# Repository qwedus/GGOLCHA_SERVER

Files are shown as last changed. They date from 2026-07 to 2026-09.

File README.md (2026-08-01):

# GGOOLCHA Telemetry System

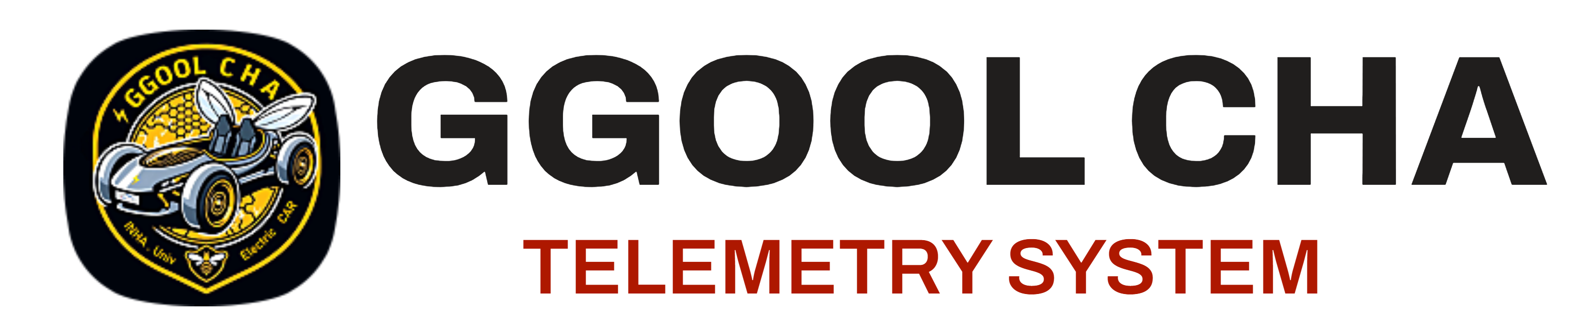
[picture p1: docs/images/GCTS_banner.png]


DIY wireless data logging platform for Team GGOOLCHA

## Features

* 📡 Full wireless support
   * Real-time telemetry
   * Download recorded data 
   * Transmit User Events
   * Transmit CAN messages
   * Configure device (e.g. CAN bit rate)

* 📀 Up to 100 Hz data rate with various signals
   * 1x CAN 2.0(A/B)
   * 1x External GPS
   * 1x Internal 6-axis Accelerometer & Gyroscope
   * 4x Digital input channels
   * 6x Analog input channels
   * 1x Power supply voltage sensor
   * 1x Chip temperature sensor

* 💡 Customizable web-based data analysis tool
* 🍺 Fully Open-source & Open-hardware under the Beerware license

## Preview

[Web Control Hub](https://v2.monolith.luftaquila.io) for live telemetry, data viewer and device/ui configurations.

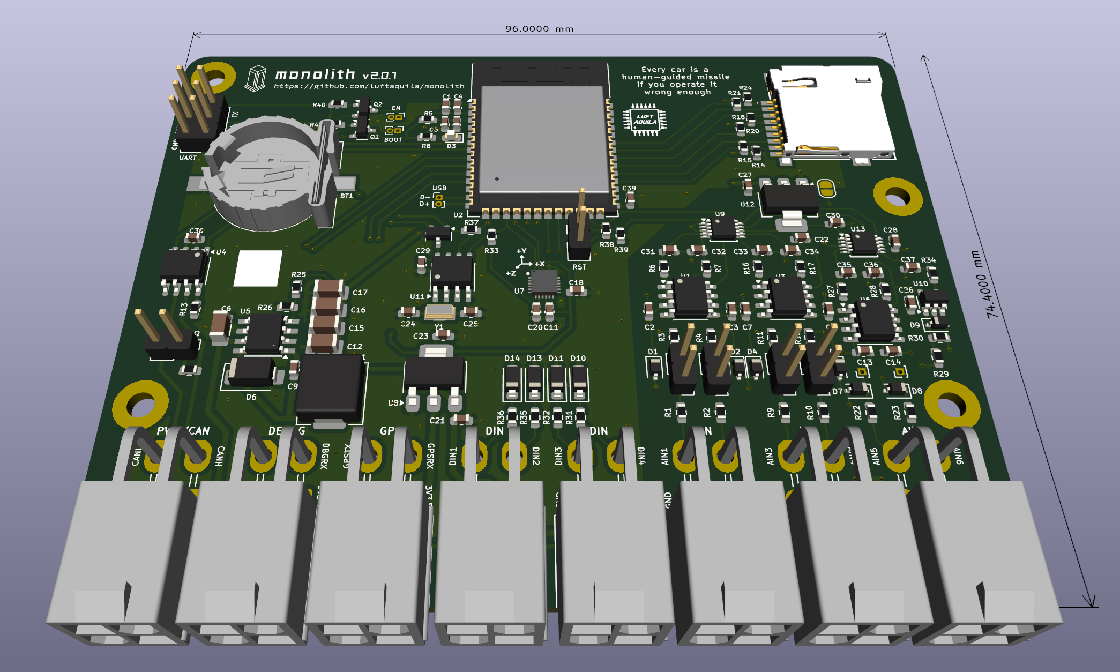
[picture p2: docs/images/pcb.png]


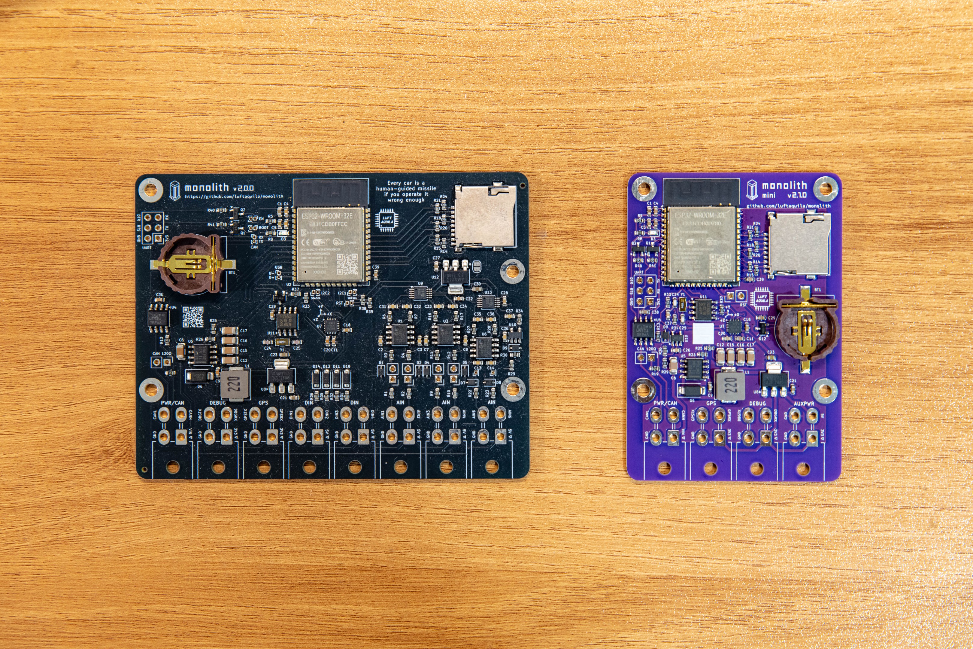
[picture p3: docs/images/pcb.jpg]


## Documentation

[Full documentation](https://v2.monolith.luftaquila.io/docs) for DIY and usage details.

## Others

The name of the project was inspired by Arthur C. Clark's novel `2001: A Space Odyssey`.

## Sponsors



The prototype PCBs for the Monolith v1, v2, and v2 mini were sponsored by [PCBWay](https://www.pcbway.com/).

For the detailed review of the manufactured PCB, see [here](https://v2.monolith.luftaquila.io/docs/#sponsor).

### Individuals

<!-- sponsors --><a href="https://github.com/">User avatar: Private Sponsor</a><!-- sponsors -->

## 한계
현재는 stm32 -> esp32 -> mqtt 브로커 -> 서버 -> 프론트
stm32 -> esp32간 통신방식은 서버와 무관

JSON payload로 전달받을 경우
서버 JSON parser를 만들면 서버수정이 불필요할수도 있겠으나
 * JSON자체가 바이너리보다 무거움
 * JSON자체 오버헤드 존재등
 * WiFi자체 유선대비 지연/패킷손실 불규칙
 
 등등의 고빈도,고비용의 문제로 ESP32로는 바이너리 포맷이 적합하다고 판단.

따라서 현재로써는 Binary Payload방식을 이용할수밖에 없고 센싱을 금년과 다르게 할 경우 서버쪽 코드(protocol.js) 수정 불가피.

금년도에 사용한 ESP32의 경우 대역폭이 2.5GHZ로 낮았기때문에 호환성 최대화를 이용하여 아이폰 핫스팟이용(교내 와이파이 대역폭 5GHZ라 이용불가)

{2026년 3기 기준}

## Monolith v2 대비 변경사항
실시간 모니터링이 아닌 실시간 로깅을 목표로 했기때문에

브라우저가 MQTT브로커에 pub/sub클라이언트로 직접 접속하는 구조에 데이터 write가능한 상시 프로세스 추가구현(MQTT Logger)
시계열 DB인 influxDB 추가 구현및 운영.

다음 기수 이용을 고려하여 로컬보단 클라우드(AWS) 단일인스턴스내에 배포

deploy.yml 추가를 통해 CI/CD 구현. (GitHub 수정 즉시 서버 반영)  

센싱을 금년과 다르게 할 경우 (protocol.js)의 수정이 불가피하기에 수정의 편리함을 위해 기존에 하드 코딩되어있던 부분을 FIELD_SCHEMA 구조로 리팩토링
(필드의 추가/삭제의 경우 FIELD_SCHEMA만 변경하면 됨)

## 인프라 구축 과정

## LICENSE

For non-commercial use only:

```
"THE BEERWARE LICENSE" (Revision 42):
LUFT-AQUILA wrote this project. As long as you retain this notice,
you can do whatever you want with this stuff. If we meet someday,
and you think this stuff is worth it, you can buy me a beer in return.
```

<br>

<picture>
  <source media="(prefers-color-scheme: dark)" srcset="https://api.star-history.com/svg?repos=luftaquila/monolith&type=Date&theme=dark" />
  <source media="(prefers-color-scheme: light)" srcset="https://api.star-history.com/svg?repos=luftaquila/monolith&type=Date" />
  Star History Chart
</picture>

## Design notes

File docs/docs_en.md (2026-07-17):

# Monolith v2

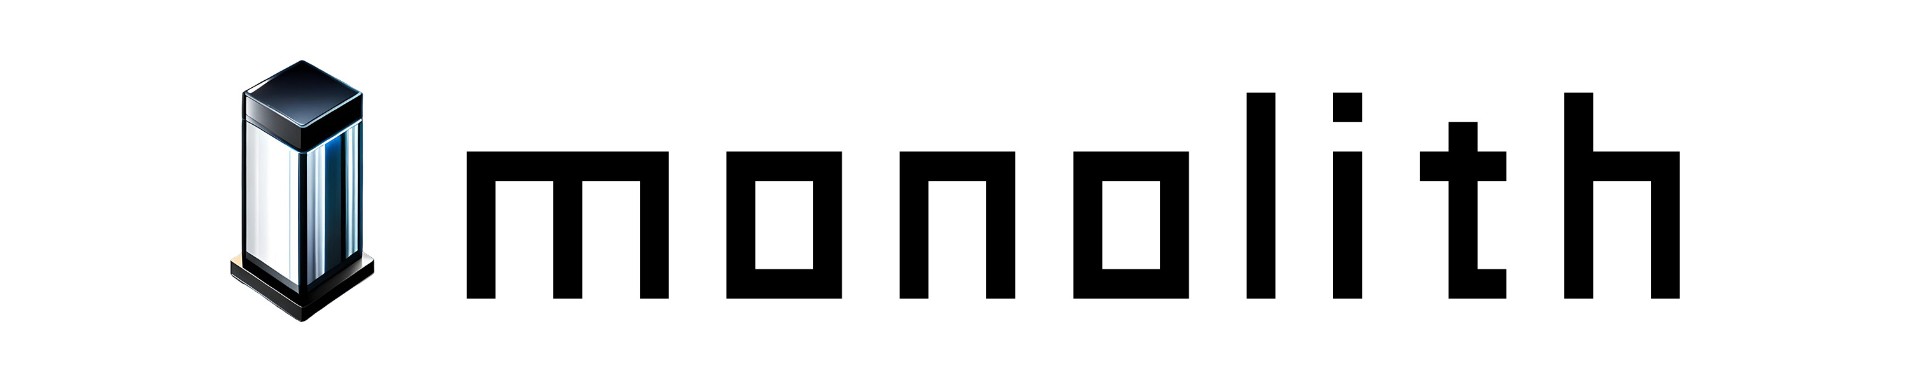
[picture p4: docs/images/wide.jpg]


## Overview

Monolith is a wireless data logger platform with logger hardware (a.k.a. TMA-1) and web-based [Control Hub](https://v2.monolith.luftaquila.io).

The project's inspiration was to help students (me 3 years ago) participating in Formula Student and Baja easily collect data from their cars, but it can be used in any other applications, or just as an ESP32-S3 development board.

This is an open-(source & hardware) project, licensed under the 🍺[Beerware License](https://spdx.org/licenses/Beerware.html) for all non-commercial use. You can find more details on the [GitHub](https://github.com/luftaquila/monolith).



### Features

📡 Full wireless support

* Real-time telemetry
* Download recorded data
* Transmit User Events
* Transmit CAN messages
* Configure the device (e.g., CAN bit rate)

📀 Up to 100 Hz data rate across various signals

* 1x CAN 2.0(A/B)
* 1x External GPS
* 1x Internal 6-axis accelerometer & gyroscope
* 4x Digital input channels<sup>1</sup>
* 6x Analog input channels<sup>1</sup>
* 1x Power supply voltage sensor
* 1x Chip temperature sensor

<sup>1</sup> Not supported on mini version.

💡 Customizable web-based data analysis tool

All wireless features require a Wi-Fi connection to the Internet.

Q. But where to get it on the car?\
A. Bring a phone with Wi-Fi hotspot on board!
It will also make you available to blame the driver by calling them while driving.

### Preview

#### Compare with v1

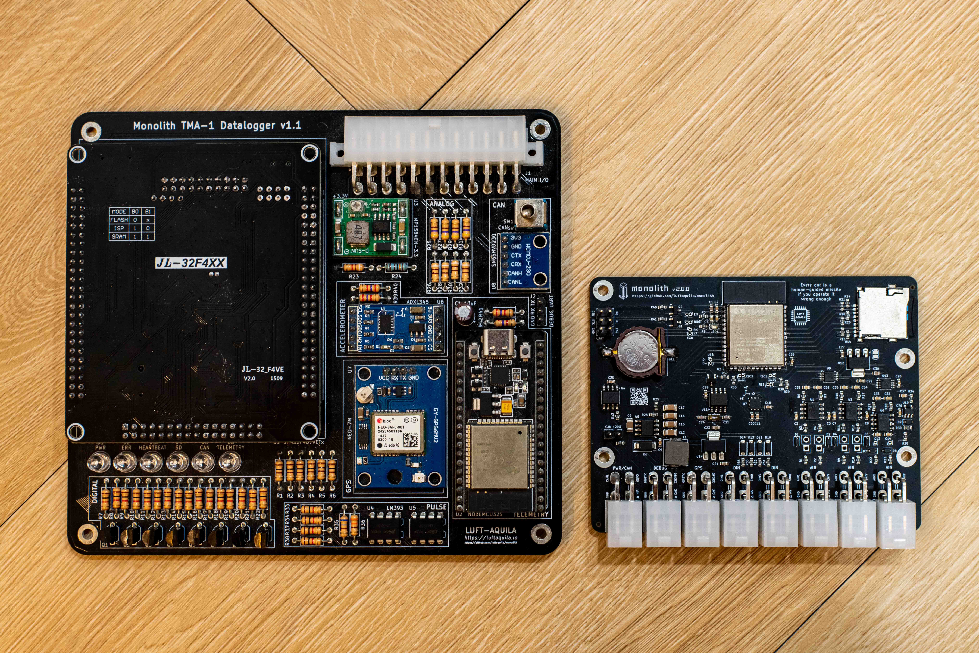
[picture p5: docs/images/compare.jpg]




* Size and build cost reduced to about 1/3.
* Better performance and telemetry stability.
* Wireless data download & configuration.
* Remote user event & CAN message transmit.

#### Original vs mini

The Mini version is nearly half the size of the Original, with a footprint even smaller than a credit card.

To achieve this, the digital and analog input channels have been removed. However, all other functionalities remain identical.

## Do It Yourself!

Monolith is an open-hardware project. It is highly recommended to build the TMA-1 PCB yourself.

KiCAD schematic and layout are available at [device/hardware](https://github.com/luftaquila/monolith/tree/main/device/hardware).

### Build TMA-1 PCB

1. Download and unzip `monolith-{version}.zip` from the [Release](https://github.com/luftaquila/monolith/releases/latest).
1. Go to [JLCPCB](https://jlcpcb.com/) and upload *pcb/gerbers/GERBER-monolith.zip*.
1. Turn on the `PCB Assembly` toggle switch at the bottom.
    * Select `2D barcode with 5*5mm, Specify Position` option for `Mark on PCB`.
    * No need to adjust any other options. Maybe choose a color you prefer?<br>
    <small>Please just keep in mind that black is the best color ever for the TMA-1 and all other PCBs around the Earth.</small>
1. Upload `BOM-monolith.csv` and `CPL-monolith.csv`.
1. Place an order and enjoy some beer until the shipment arrives.
1. Solder 8x [Molex 5569-04A2(39300040)](https://www.molex.com/en-us/products/part-detail/39300040) connectors to the PCB.
1. Insert a CR1220 battery and an SD card.
1. `goto 'Upload Firmware';`

<details>

<summary>⭐ Secret tip</summary>

<h4>Warm Secret Tip</h4>

To reduce PCB manufacturing cost, exclude the `BT1` CR1220 battery holder, `L1` power inductor and `U2` ESP32-S3 module from assembly.
Instead, purchase and solder these parts manually.



Skipping `BT1` and `L1` will save you a bottle of beer (extended components fee $3 each).

In particular, ESP32-S3 module requires **Standard PCB Assembly** instead of **Economic PCB Assembly**, which doubles the price💸!

Soldering ESP32 manually may be a bit challenging for the newbies, but it will be worth it.
Without those parts, the cost is about $60 for 5x assembled PCBs.

You should use the ESP32-S3-WROOM-1 module, and do ***NOT*** use the module with 8MB+ PSRAM (R8/R16 variants). Just solder the cheapest one (ESP32-S3-WROOM-1-N4).

If you only need a few PCBs, set PCBA Qty to 2 instead of 5.
It will save you another $20 and give you 3 empty PCBs as souvenir.

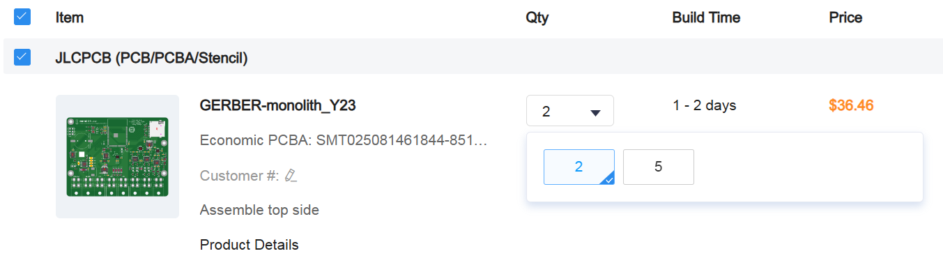
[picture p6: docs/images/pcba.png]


</details>

### Upload Firmware

1. Prepare a 3.3V UART to USB converter.
    * ⚠️ The converter **MUST** have both `DTR` and `RTS` in addition to `RX` and `TX`.
    * ⚠️ Do **NOT** use a converter with 5V output unless it has a 3.3V voltage selector.
1. Solder a 2x3 2.54mm pin header to the board's UART connector.
1. Connect each pin of the Monolith PCB with the following pinout:
    * `3V3`, `GND`, `DTR`, `RTS`: corresponding pins on the converter.
    * `RX`, `TX`: cross-connect with the converter (`RX` ↔ `TX`).
1. Download and unzip `monolith-{version}.zip` from the [Release](https://github.com/luftaquila/monolith/releases/latest).
1. Run `flash.sh` (Linux/macOS) or `flash.bat` (Windows).
    * `python` is required to execute.

### Prepare Server

The TMA-1 and the Control Hub need an MQTT server (broker) to communicate.

For your sake, there is a free default server [v2.monolith.luftaquila.io](https://v2.monolith.luftaquila.io).

To use the default server, send an email to [mail@luftaquila.io](mailto:mail@luftaquila.io) with your school name, desired channel name and channel key. Please note that the default server may become unavailable at any time for any reason.

<details>

<summary>I want to set up the server on my own.</summary>

<h4>Deploy (Optional)</h4>

If you want to stay away from me, use a commercial MQTT broker service or deploy your own server by following the guide below.

Here, I'll assume you have experience with server things. (DNS records, firewalls, etc.).

***Prerequisites***: A Linux machine with [Docker Engine](https://docs.docker.com/engine/install/) and [Node.js](https://nodejs.org/en/download).
Don't have one? Go get [one](https://www.oracle.com/cloud/free/).

It is *theoretically* possible to run with Docker Desktop and a Windows machine, but I haven't tried it.

Run the commands below, and don't forget to replace `<YOUR_CHANNEL_NAME>` with a cool name.

```sh
sudo apt install -y mosquitto
git clone https://github.com/luftaquila/monolith.git

cd monolith/web
npm install
npm run build

cd ../server/config
# set your channel key as the password
mosquitto_passwd -c mosquitto.passwd <YOUR_CHANNEL_NAME>

cd ..
cp .env.example .env
vi .env # set `ACME_EMAIL` and `DOMAIN_NAME` to your own

sudo docker compose up -d
```

##### Server Announcement

Set the `ANNOUNCEMENT` environment variable in the `.env` file to display a notice popup when users open the Control Hub.

```sh
ANNOUNCEMENT=Scheduled maintenance: 2025-01-15 02:00 ~ 04:00 (UTC)
```

</details>

## Usage

### Device (TMA-1)

As mentioned in the DIY section above, all 8x connectors on the PCB are [Molex 5569-04A2(39300040)](https://www.molex.com/en-us/products/part-detail/39300040).
The mating part is [Molex 5557-04R(39012040)](https://www.molex.com/en-us/products/part-detail/39012040), which uses the [Molex 5556T(39000038)](https://www.molex.com/en-us/products/part-detail/39000038) as a crimp terminal.

The pinout for each connector is labeled on the PCB. Please remember that the misconnection of the pins may cause ***PERMANENT*** damage to the device.

#### Specifications

| |MIN|TYP|MAX|UNIT|
|:-:|:-:|:-:|:-:|:-:|
|Supply Voltage|5.5| |36|V|
|Power Consumption| |0.5|1|W|
|Digital Input Voltage|0|5|8.5|V|
|Analog Input Voltage <small>(1)</small>|-0.3| |7.2|V|
|Accelerometer Range|-8| |8|g|
|Gyroscope Range|-500| |500|°/s|

<small>(1) When voltage divide jumper is connected. 1/2 for AIN5, AIN6 and channels with no jumper.</small>

#### Wi-Fi

TMA-1 requires a 2.4GHz Wi-Fi connection to provide wireless features such as live telemetry and remote record downloads.

However, the data logging function works without Wi-Fi.
To use it offline, remove the SD card and mount it on your computer after driving.

TMA-1 automatically sets its internal clock via SNTP, so you must connect it to the Internet at least once for time synchronization.

##### Initial Setup

1. Power up the device.
1. On first boot, it creates its own Wi-Fi access point (AP) named `Monolith v2 XXXXXX`. Password is `monolith`.
1. Connect to that AP. The setup page will automatically open in your browser. If it doesn't, navigate to [http://192.168.4.1](http://192.168.4.1) manually.\
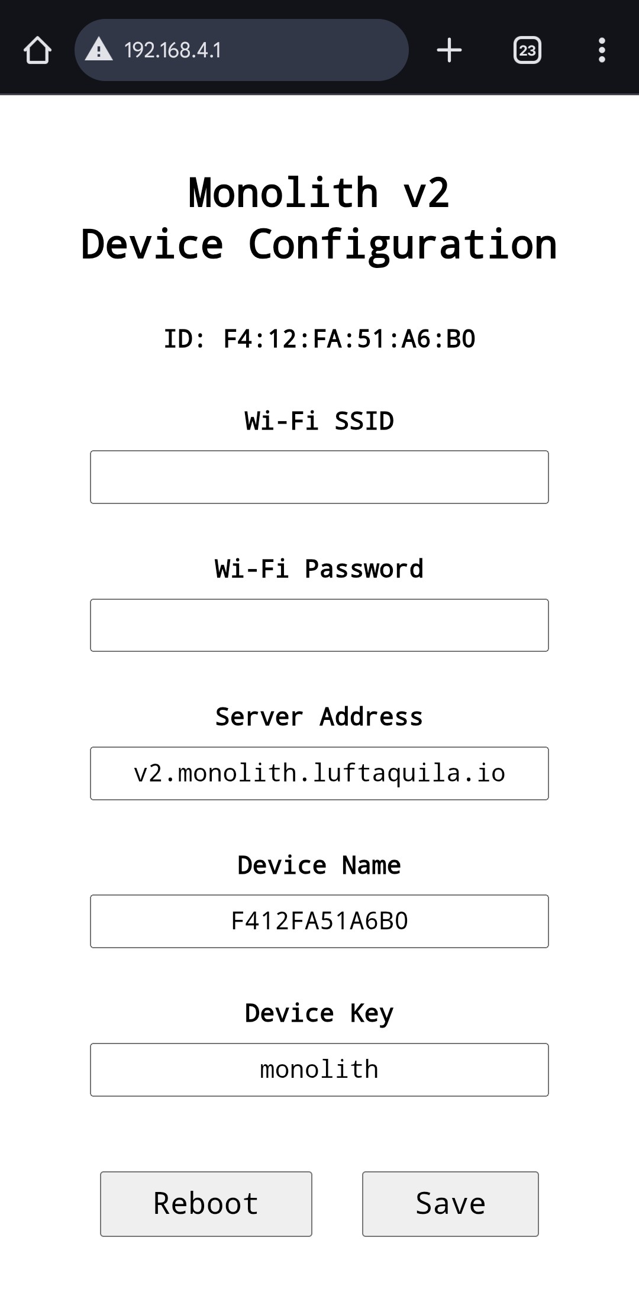
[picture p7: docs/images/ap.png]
    
1. Set `Wi-Fi SSID` and `Wi-Fi Password` to the phone's Wi-Fi Hotspot that TMA-1 will connect to while driving (the phone that the driver will bring onboard).
1. Set `Server Address` to your server.
    * The default server [v2.monolith.luftaquila.io](https://v2.monolith.luftaquila.io) is available to the approved users only. To apply, send me an email at [mail@luftaquila.io](mailto:mail@luftaquila.io) with your school name, desired channel name and channel key.
1. Set `Device Name` and `Device Key` to match the values you emailed me.
1. Click `Save`, then click `Reboot`.

TMA-1 will try to connect to the configured Wi-Fi network after rebooting.

##### Reset

To reset the Wi-Fi and server configuration, short the `RST` jumper on the PCB for 3 seconds and release.
This restores Wi-Fi, server, device name/key, and all configuration data to factory defaults.

After reset, proceed to the `Initial Setup` step above.

#### Power & CAN

The `PWR/CAN` port supplies power to the TMA-1 and provides a CAN connection.

`VIN` and `GND` are the power supply pins. The device draws about 0.5W during active operation (40mA @12V).

A PCB jumper labeled `CAN 120Ω` enables the on-board termination resistor. Set it according to your CAN bus design.
There must be 2x 120Ω resistor on the bus, one at each end, resulting in 60Ω between `CANH` and `CANL` line.

#### GPS

TMA-1 supports an external GPS module for location tracking.

Connect the `GPS` port to a GPS module with UART support using the following pinout:

* `3V3` and `GND` to module power
* `GPSRX`, `GPSTX`: cross-connect with the module

Currently, only U-BLOX NEO-6M/7M/8M modules are supported. Support for additional modules may be added in the future on demand.

#### Debug Output

`DEBUG` port is inactive and reserved for custom use.

It is intended for outputting the recorded logs to other onboard MCUs (e.g., a cockpit display).

Electrically, it provides a 3.3V 0.5A power rail and two free GPIO lines. It's up to you to customize how you use this connector.

#### Digital & Analog

TMA-1 provides 4x digital inputs and 6x analog inputs, with 5x 5V power rails that can supply 2.5A in total.

##### Digital Inputs

* Logic LOW: 0 ~ 0.8V
* Logic HIGH: 2.4 ~ 8.5V

It can withstand brief higher voltages, but continuous operation is limited to 8.5V.

##### Analog Inputs

Absolute maximum input voltage of the analog channel is 3.6V.

Meanwhile, AIN1 to AIN4 have a selectable 1/2 voltage divider circuit.
It is enabled by connecting the jumper in front of the each AIN channel on the PCB.
The maximum input voltage is increased to 7.2V if the divider is enabled.

Therefore, sensors with the maximum output voltage of 5V are only applicable when the divider is enabled.

Since AIN5 and AIN6 have no voltage divider, their maximum voltage is fixed at 3.6V.

### Control Hub

Control Hub is at [https://v2.monolith.luftaquila.io](https://v2.monolith.luftaquila.io) and you can use it for free any time.

#### Live Telemetry

Before using Live Telemetry, set the server information in the `Device Configuration` tab.

Also, to view the incoming CAN data, you need to set the CAN Decoders in the `UI Configuration` tab first.

Once the server is configured correctly and the TMA-1 is online, there is nothing else to do here. Everything will work like magic.

The GPS card shows live position data with a `Fix` / `No Fix` tag indicating satellite lock status. You can switch the trail visualization between `Speed` mode (green=slow, red=fast) and `Time` mode (indigo=old, green=recent).

##### Console

You can send a user event or a CAN message to the device.

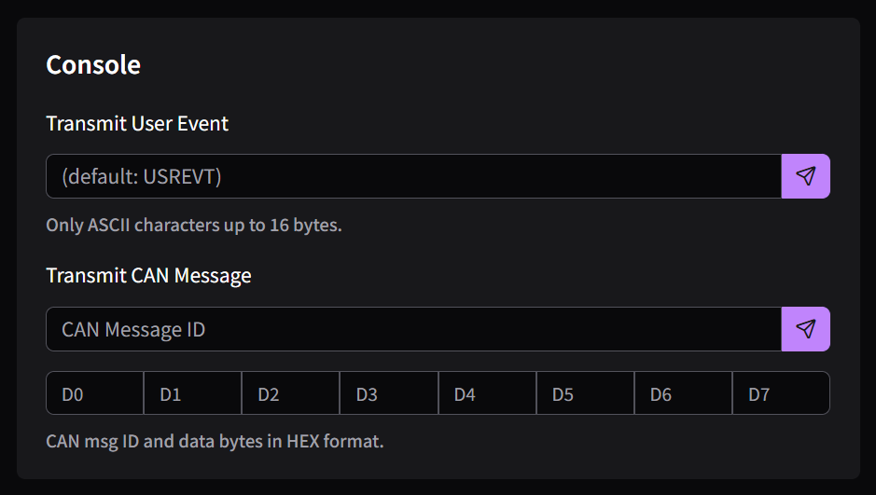
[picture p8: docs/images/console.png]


* User Events
    * A user event marks some meaningful points that can help with later data review.
    * To send a user event, fill in the event name and click the send button.
    * If the event name is empty, it will be recorded as `USREVT`.
    * Only ASCII characters up to 16 bytes are allowed.

* CAN message
    * Enter the CAN message ID (11/29 bits) and the data bytes to send.
    * Click the send button. `0x00` will be sent for the empty data byte fields.

#### Data Viewer

To review your drive, you need to download the recorded data first.
Refer to the `Data Downloader` section in the `Device Configuration` tab to download data.

* Click `Select` and open a `*.log` file that you've downloaded.
* In the `Graph` card, toggle the input category button or the signal name of the legend to see the graph.
* The `GPS` card displays the vehicle's trajectory with a color gradient trail. Switch between `Speed` (green=slow, red=fast) and `Time` (indigo=old, green=recent) modes. Use the slider to scrub through the data and view position, speed, and heading at any point.
* The `CAN` card displays statistics for all recorded CAN messages: message ID, total count, average interval (Hz / ms), DLC, and last data bytes.

To view the recorded CAN data, set the CAN Decoders in the `UI Configuration` tab first.

#### UI Configuration

You can adjust the visibility of the cards in the Live Telemetry and the Data Viewer.
Also, you can set the input signal's name, unit and value multipliers.

Refresh the page for the changes to take effect.

##### Import/Export

Export/import the current UI configuration across devices/browsers.

##### Display

Control the visibility of the cards in each view.

##### Units

Manage custom units that can be used for analog and CAN data.

##### Digital

This section enables you to change the channel name. (e.g., `RUINED IF ON` instead of `DIN1`)

##### Analog

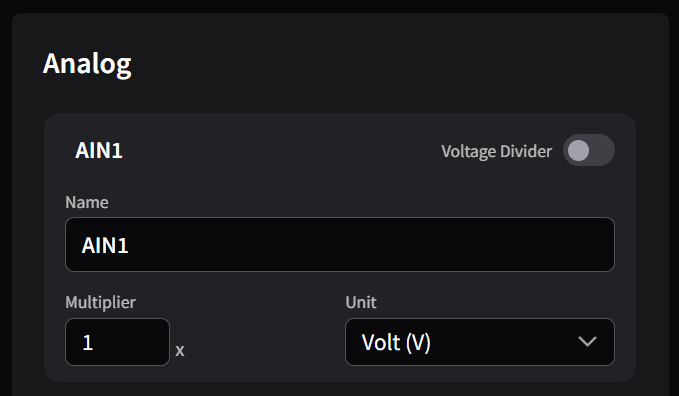
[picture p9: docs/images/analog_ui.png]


* `Name`: The name shown on the graphs.
* `Voltage Divider`: Turn on if you have a divider jumper connected on your PCB.
* `Multiplier`: The number multiplied to the measured voltage. Edit it if you have:
    * Another voltage divider circuit for the sensor.
    * A formula to calculate the original physical value.
* `Unit`: An appropriate unit of the value. Add one at the `Units` card if you don't have it.

##### CAN

Manage CAN message decoders. A decoder extracts useful data from the CAN message bytes.

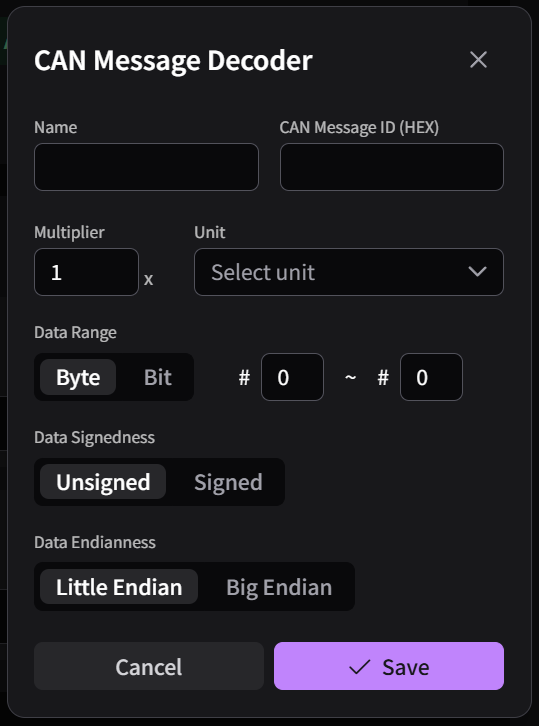
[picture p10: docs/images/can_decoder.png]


* `Name`: The name shown on the graphs.
* `CAN Message ID`: The message ID that desired data is included.
* `Multiplier`: The number multiplied to the original value.
* `Offset`: The number added after multiplication. Final value is `multiplier × original + offset`. Default is `0`.
* `Unit`: The data unit that added on the `Units` card.
* `Data Range`: The part of the CAN payload that contains the data.
    * The CAN payload has a maximum length of 8 bytes.
        * `Byte` mode: The possible range is #0 to #7.
        * `Bit` mode: The possible range is #0 to #63.
        * To select a single byte/bit, set the start and end range to the same value.
* `Data Signedness`
    * `Unsigned`: Decode the data as an unsigned value.
    * `Signed`: Decode the data as a 2's complement value.
* `Data Endianness`
    * Only available in `Byte` mode.
    * Defines the endianness of multi-byte data.
* `Data Filter` / `Data Mask` (optional): Hex values to filter CAN messages by payload content. Only messages where `(data & mask) == filter` are decoded. Both must be specified together or left empty.

#### Device Configuration

This section configures the server for the Control Hub and the device peripherals.

The configurations will be automatically loaded if the device is online.

##### Server

* `Address`: The server for the Control Hub.
* `Name` / `Key`: Channel name and key.

All values must match the values configured to the device during the `Device - Initial Setup` sequence.

The server will be automatically connected after you click the save button.

##### Device

* `SSID` / `Password`: The Wi-Fi network that the device will connect to.
* `Timezone`: The POSIX timezone string for your location. Use the [converter](https://phpsecu.re/tz/)'s `TZ_INFO` value.
    * It is used to determine the log file name's time. Recorded logs use the UTC time, so it won't be affected.
* `T. Interval`: The interval at which the device transmits telemetry.

##### Inputs

Controls whether the digital/analog input channels are logged or not.

##### CAN

* `Enabled`: Whether the CAN bus is logged or not.
* `Bit rate`: The bus baud rate.
* `Filter`: The expected message ID (11/29 bits)
* `Mask`: The filtering rule for each bit of the filter.
    * `0`: The corresponding filter bit must match to pass.
    * `1`: The corresponding filter bit is ignored (don't care).

Refer to the *Acceptance Filter* section of the [ESP32-S3 API Reference](https://docs.espressif.com/projects/esp-idf/en/v5.4.2/esp32s3/api-reference/peripherals/twai.html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) for the detailed explanation of the `Filter` and `Mask`. All CAN messages will be accepted by default.

##### GPS

* `Enabled`: Whether the GPS location is logged or not.
* `Device`: Select the device type. Only `UBLOX` is currently supported.

##### [Danger Zone](https://www.youtube.com/watch?v=siwpn14IE7E)

* `Refresh`: Loads the device's configuration.
    * All changed configurations require a device restart to be applied.
    * If you refresh before restarting, the previous value will be loaded.
* `Restart`: Restart the device.
* `Reset`: Reset the device. Same as shorting the `RST` jumper on the board.

##### Data Downloader

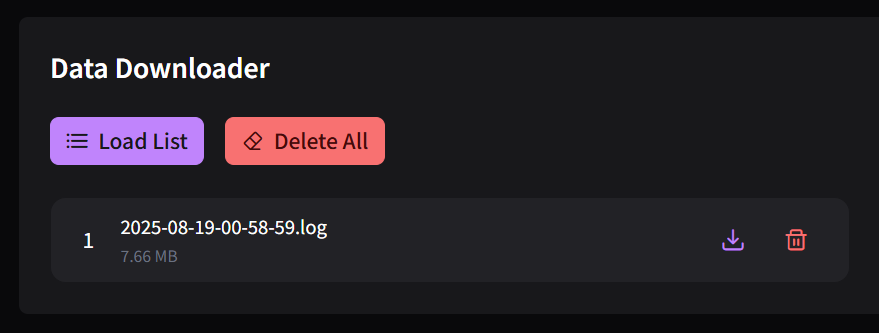
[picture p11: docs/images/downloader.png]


* `Load List`: Lists all recorded log files except the current boot session.
* `Delete All`: Deletes all recorded log files except the current boot session.

After loading the file list, click the download button to download a specific file.

## Development

This section is for computer-guys who wants to modify the software on their own.

<details>

<summary>Open the magic</summary>

<h3>Firmware</h3>

1. Star the [GitHub repository](https://github.com/luftaquila/monolith).
1. Install [ESP-IDF](https://docs.espressif.com/projects/esp-idf/en/stable/esp32s3/get-started/index.html) And run the following commands.

```
git clone https://github.com/luftaquila/monolith.git
cd monolith/device/firmware
make build
make run   # build & flash
```

<h3>Control Hub</h3>

1. Star the [GitHub repository](https://github.com/luftaquila/monolith).
1. Run the following commands:

```
git clone https://github.com/luftaquila/monolith.git
cd monolith/web
npm install
npm run vite
npm run build
```

</details>

## Sponsor

All PCBs for the Monolith project were supported by PCBWay for the prototyping.



When selecting white, black, or matte PCB colors, the boards must meet a minimum copper-to-copper spacing requirement of 0.22 mm. In the most recent v2 mini PCB, which uses the MPU-6500 accelerometer, the pin pitch is 0.2 mm. Since I ordered the black one, I received an email that it was not possible to produce. The simplest solution was to change the color to green, blue, red, or purple. So I took the rarest one - purple.

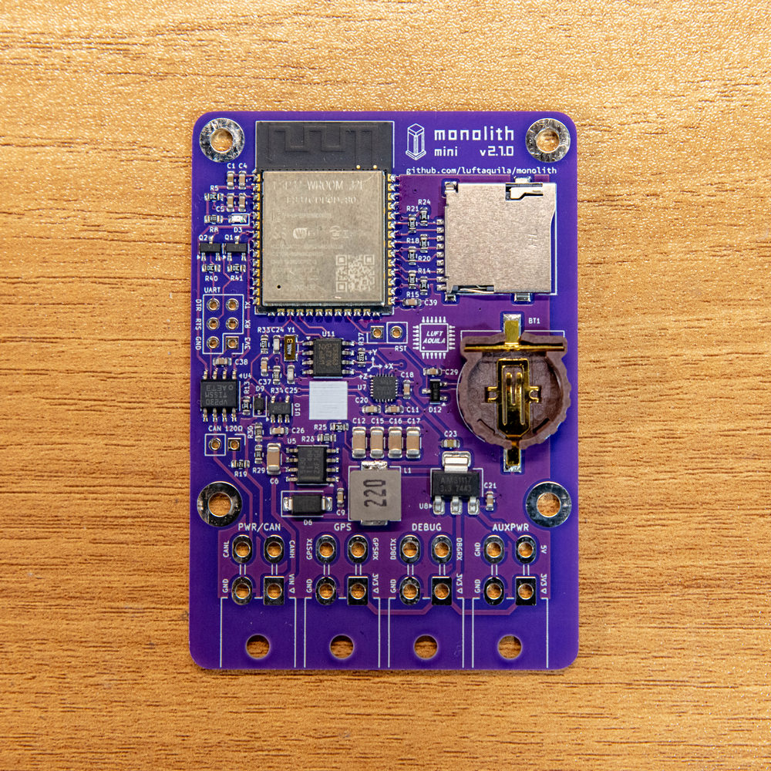
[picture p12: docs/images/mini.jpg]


After that, I received mails about the quotation, BOM list, and the issues present. Once manufacturing was complete, I received photos of the finished boards, and it took exactly two weeks from the order date to the shipping date.

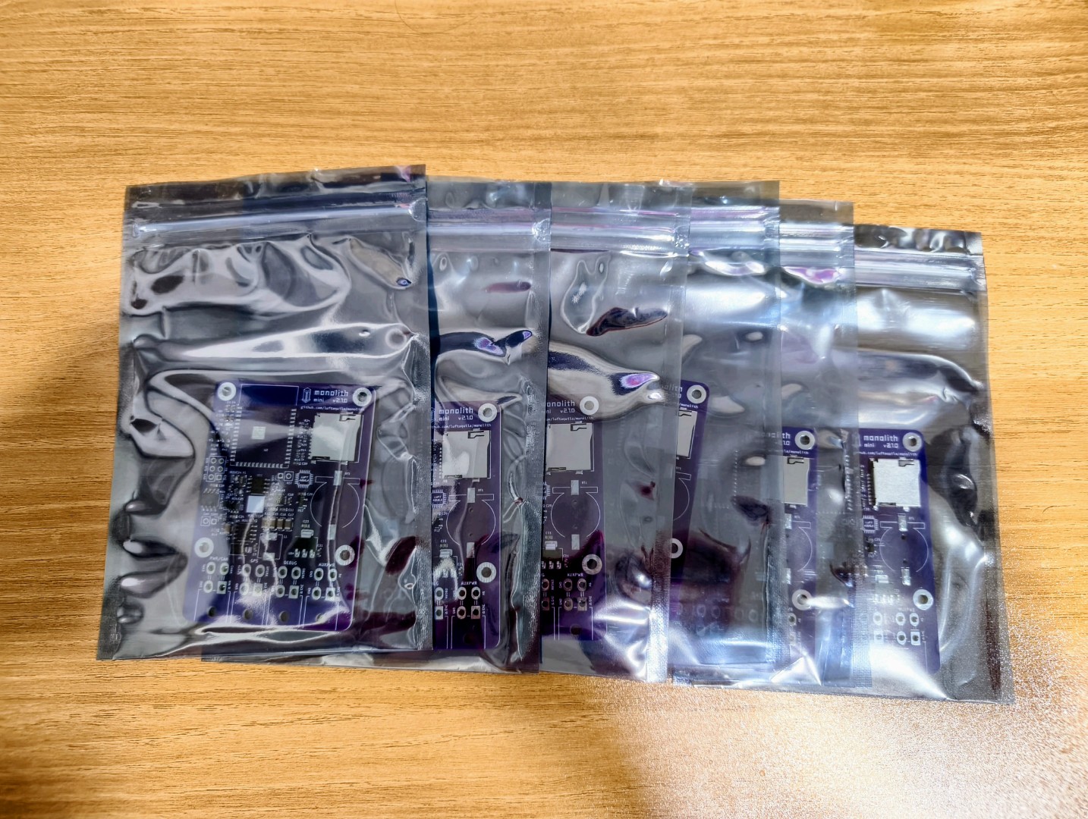
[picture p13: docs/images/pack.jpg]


The delivered PCBs came individually packed in anti-static bags. It was surprising as I used to receive a bunch of boards wrapped together in bubble wrap. The tested board worked perfectly, and all SMD components were properly soldered with no issues such as solder bridges. Even the pads for the unassembled components came pre-tinned, making manual soldering much easier. The color of the board was beautiful as well.

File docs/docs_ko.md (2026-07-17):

# Monolith v2



## 개요

모노리스는 TMA-1 데이터로거와 웹 기반 [Control Hub](https://v2.monolith.luftaquila.io)로 구성된 무선 데이터로깅 플랫폼입니다.

Formula Student 및 Baja Student 대회에 참가하는 학생들의 차량 데이터 수집을 위해 개발되었으나, 다른 분야의 데이터 계측이나 ESP32 개발 보드로도 활용할 수 있습니다.

모든 소스코드와 하드웨어 설계도가 [GitHub](https://github.com/luftaquila/monolith)에 공개되어 있으며, 비상업적 용도에 한해 🍺[Beerware License](https://spdx.org/licenses/Beerware.html)로 자유롭게 사용할 수 있습니다.



### 기능

📡 무선 통신 지원

* 실시간 텔레메트리
* 로그 데이터 원격 다운로드
* 원격 사용자 이벤트 전송
* 원격 CAN 메시지 전송
* 장치 설정 변경

📀 최대 100 Hz 데이터로깅

* 1x CAN 2.0(A/B)
* 1x 외장 GPS 모듈
* 1x 6축 가속도계 & 자이로
* 4x 디지털 입력<sup>1</sup>
* 6x 아날로그 입력<sup>1</sup>
* 1x 전원 전압 센서
* 1x 칩 온도 센서

<sup>1</sup> mini 버전에서는 지원하지 않습니다.

💡 웹 기반 데이터 분석 도구

모든 무선 통신 기능은 Wi-Fi 연결이 필요합니다. 차량에서 사용하기 위해서는 드라이버가 Wi-Fi 핫스팟을 켠 휴대폰을 가지고 타야 합니다.

### 미리보기

#### v1 대비 변경사항





* PCB 크기와 제작 비용이 모두 3분의 1로 줄었습니다.
* 데이터 처리 성능과 무선통신 안정성이 대폭 개선되었습니다.
* 원격으로 로그를 다운로드할 수 있습니다. 데이터를 확인하기 위해 SD카드를 뽑을 필요가 없습니다.
* 원격으로 사용자 이벤트를 로그에 삽입하거나 CAN 메시지를 전송할 수 있습니다.
* 펌웨어 플래싱 없이도 원격으로 데이터로거 설정을 변경할 수 있습니다.
* 웹 UI로 모든 기능을 제공하므로 전용 프로그램을 따로 설치할 필요가 없습니다.

#### Original vs mini

Mini 버전은 Original 대비 절반 가까운 크기로, 신용카드보다도 작은 크기를 자랑합니다.

대신, 작은 크기를 위해 디지털 및 아날로그 입력 채널이 제거되었습니다. 그 외의 다른 기능은 모두 동일합니다.

## Do It Yourself!

모노리스 TMA-1은 회로도와 PCB 레이아웃이 모두 [device/hardware](https://github.com/luftaquila/monolith/tree/main/device/hardware) 에 공개되어 있습니다.

아래 방법으로 PCB를 직접 제작할 수 있으나, 급하게 필요한 경우를 위해 [https://smartstore.naver.com/luftaquila](https://smartstore.naver.com/luftaquila) 에서도 판매하고 있습니다.

### TMA-1 PCB 제작

1. [Release](https://github.com/luftaquila/monolith/releases/latest)에서 `monolith-{version}.zip`을 다운받고 압축을 해제합니다.
1. [JLCPCB](https://jlcpcb.com/)에서 *pcb/gerbers/GERBER-monolith.zip*을 업로드합니다.
1. 하단의 `PCB Assembly` 스위치를 켭니다.
    * `Mark on PCB`에서 `2D barcode with 5*5mm, Specify Position`을 선택합니다.
    * 다른 옵션은 건드릴 필요가 없습니다. 기판 색상만 원하는 대로 선택합니다.
1. `BOM-monolith.csv`와 `CPL-monolith.csv`를 업로드하고 기판을 주문합니다.
1. PCB에 [Molex 5569-04A2(39300040)](https://www.molex.com/en-us/products/part-detail/39300040) 커넥터 8개를 납땜합니다.
1. CR1220 배터리와 SD 카드를 삽입합니다.
1. `펌웨어 업로드` 항목으로 이동합니다.

<details>

<summary>⭐ PCB 제작 팁</summary>

<h4>PCB 제작 팁</h4>

PCB 제작비를 줄이려면 `BT1` CR1220 배터리 홀더, `L1` 전원부 인덕터, `U2` ESP32 모듈을 조립 항목에서 제외하고, 해당 부품을 따로 구매해 직접 납땜하세요.



`BT1`과 `L1`을 빼면 부품 종류 1개당 extended component fee $3 을 아낄 수 있습니다.

특히, ESP32-S3 모듈은 조립하려면 **Economic PCB Assembly** 대신 **Standard PCB Assembly**가 필요해 가격이 두 배가 됩니다.

ESP32 모듈은 초심자에게는 직접 납땜하기가 다소 어려울 수 있으나, 이렇게 하면 $60로 완성된 PCB 5장을 생산할 수 있습니다.

반드시 ESP32-S3-WROOM-1 모듈을 사용해야 하며, 8MB 이상의 PSRAM이 내장된 모듈(R8/R16)은 사용할 수 없습니다. 그냥 가장 저렴한 ESP32-S3-WROOM-1-N4 를 사용하면 됩니다.

PCBA Qty를 5에서 2로 조정하면 완성된 기판이 2장만 오는 대신 $20 정도를 추가로 절약할 수 있습니다.



</details>

### 펌웨어 업로드

1. 3.3V UART to USB 컨버터를 준비합니다.
    * ⚠️ 컨버터에는 `RX`, `TX` 외에도 `DTR`, `RTS` 핀이 **반드시** 있어야 합니다.
    * ⚠️ 5V 컨버터는 별도의 3.3V 전압 선택 스위치가 없다면 사용할 수 없습니다.
1. 보드의 UART 커넥터에 2x3 2.54mm 핀 헤더를 납땜합니다.
1. 모노리스의 각 핀을 다음과 같이 연결합니다.
    * `3V3`, `GND`, `DTR`, `RTS`: 컨버터에 있는 같은 이름의 핀과 연결
    * `RX`, `TX`: 컨버터의 핀과 서로 교차하여 연결 (`RX` ↔ `TX`)
1. [Release](https://github.com/luftaquila/monolith/releases/latest)에서 `monolith-{version}.zip`을 다운받고 압축을 해제합니다.
1. `flash.sh` (Linux/macOS) 또는 `flash.bat` (Windows) 파일을 실행합니다.
    * `python` 이 설치되어 있어야 합니다.

### 서버 준비

TMA-1과 Control Hub가 서로 통신하려면 MQTT 서버(브로커)가 필요합니다.

기본 서버 [v2.monolith.luftaquila.io](https://v2.monolith.luftaquila.io)는 무료로 제공되며, 등록된 사용자만 이용할 수 있습니다.
사용하려면 [mail@luftaquila.io](mailto:mail@luftaquila.io) 로 학교명과 원하는 채널 이름 및 채널 키를 보내주세요.

다만, 기본 서버는 예고 없이 운영이 중단되거나 장애가 발생할 수 있습니다.

<details>

<summary>직접 서버 배포하기</summary>

<h4>서버 배포</h4>

기본 서버를 사용하지 않는다면 상용 MQTT 브로커를 사용하거나 아래 가이드를 따라 직접 서버를 배포해 사용할 수 있습니다.

아래 가이드는 DNS, 방화벽 등 서버 관련 지식이 어느 정도 있다고 가정합니다.

[Docker Engine](https://docs.docker.com/engine/install/)과 [Node.js](https://nodejs.org/en/download)가 설치된 리눅스 머신이 필요합니다.
없다면 [여기](https://www.oracle.com/cloud/free/)서 무료로 인스턴스를 만들 수 있습니다.

이론상 Docker Desktop과 Windows 머신으로도 할 수 있지만, 테스트해본 적은 없습니다.

아래 명령을 실행합니다. `<YOUR_CHANNEL_NAME>`은 사용할 이름으로 변경합니다.

```sh
sudo apt install -y mosquitto
git clone https://github.com/luftaquila/monolith.git

cd monolith/web
npm install
npm run build

cd ../server/config
# set your channel key as the password
mosquitto_passwd -c mosquitto.passwd <YOUR_CHANNEL_NAME>

cd ..
cp .env.example .env
vi .env # set `ACME_EMAIL` and `DOMAIN_NAME` to your own

sudo docker compose up -d
```

##### 서버 공지사항

`.env` 파일의 `ANNOUNCEMENT` 환경변수를 설정하면 Control Hub 접속 시 공지사항 팝업을 표시할 수 있습니다.

```sh
ANNOUNCEMENT=서버 점검 예정: 2025-01-15 02:00 ~ 04:00 (KST)
```

</details>

## 사용법

### TMA-1

모노리스 PCB의 8개 커넥터는 모두 [Molex 5569-04A2(39300040)](https://www.molex.com/en-us/products/part-detail/39300040)입니다.
상대물은 [Molex 5557-04R(39012040)](https://www.molex.com/en-us/products/part-detail/39012040)이고, 해당 커넥터의 터미널은 [Molex 5556T(39000038)](https://www.molex.com/en-us/products/part-detail/39000038)입니다.

각 커넥터의 핀 배치는 PCB에 표기되어 있습니다. 잘못 연결하면 장치가 영구적으로 손상될 수 있으니 주의합니다.

#### Specifications

| |MIN|TYP|MAX|UNIT|
|:-:|:-:|:-:|:-:|:-:|
|Supply Voltage|5.5| |36|V|
|Power Consumption| |0.5|1|W|
|Digital Input Voltage|0|5|8.5|V|
|Analog Input Voltage <small>(1)</small>|-0.3| |7.2|V|
|Accelerometer Range|-8| |8|g|
|Gyroscope Range|-500| |500|°/s|

<small>(1) When voltage divide jumper is connected. 1/2 for AIN5, AIN6 and channels with no jumper.</small>

#### Wi-Fi

TMA-1의 무선 통신 기능(실시간 텔레메트리 및 데이터 다운로드 등)을 사용하기 위해서는 2.4GHz Wi-Fi 연결이 필요합니다.

데이터로깅 기능은 Wi-Fi 연결이 없어도 동작합니다. 오프라인으로 사용하려면 주행 이후 SD 카드를 분리하여 PC에 마운트하면 됩니다.

다만 TMA-1의 내부 시계는 네트워크를 통해 SNTP로 자동 동기화되므로, 최소한 한 번은 인터넷에 연결해 시간을 동기화해야 합니다.

##### 초기 설정

1. 장치에 전원을 공급합니다.
1. 첫 부팅 시 `Monolith v2 XXXXXX` 라는 자체 Wi-Fi AP가 생성됩니다. 비밀번호는 `monolith`입니다.
1. 해당 AP에 연결하면 자동으로 설정 페이지가 열립니다. 열리지 않으면 브라우저에서 [http://192.168.4.1](http://192.168.4.1)에 직접 접속합니다.\
   
1. TMA-1이 주행 중 연결할 휴대폰(드라이버가 들고 탈 휴대폰)의 핫스팟 정보를 `Wi-Fi SSID`와 `Wi-Fi Password`에 입력합니다.
1. `Server Address`에 사용할 서버 주소를 입력합니다.
    * 기본 서버 [v2.monolith.luftaquila.io](https://v2.monolith.luftaquila.io)는 등록된 사용자만 이용 가능합니다. 사용하려면 학교명과 원하는 채널 이름 및 채널 키를 [mail@luftaquila.io](mailto:mail@luftaquila.io)로 보내주세요.
1. 이메일로 보낸 것과 동일한 값을 `Device Name`과 `Device Key`에 입력합니다.
1. `Save`를 클릭하고 `Reboot`를 클릭합니다.

재부팅 이후 TMA-1은 설정된 Wi-Fi로 연결을 시도합니다.

##### 초기화

Wi-Fi와 서버 설정을 초기화하려면 PCB의 `RST` 점퍼를 3초 이상 합선시켰다가 뗍니다.
Wi-Fi, 서버, 디바이스 이름과 키 등 모든 설정이 초기값으로 복원됩니다.

초기화 후 위 `초기 설정` 단계부터 다시 진행합니다.

#### 전원 및 CAN

`PWR/CAN` 포트는 TMA-1에 전원을 공급하고 CAN 통신 라인을 제공합니다.

전원 핀은 `VIN`, `GND`이며, 동작 중 약 0.5W(40mA @12V)를 소모합니다.

PCB의 `CAN 120Ω` 점퍼를 합선시키면 CAN 버스의 TMA-1측 종단 저항이 활성화됩니다. 사용 중인 CAN 버스의 종단 저항 구성에 맞게 설정합니다.

CAN 버스의 양 끝단에는 120Ω 저항이 각 1개씩 있어야 하며, 이에 따라 `CANH`와 `CANL` 사이의 저항은 60Ω이 되어야 합니다.

#### GPS

TMA-1은 외장 GPS 모듈을 지원합니다.

`GPS` 포트를 UART 방식 GPS 모듈에 아래와 같이 연결합니다.

* `3V3`, `GND`: GPS 모듈 전원
* `GPSRX`, `GPSTX`: GPS 모듈의 `TX` 및 `RX` 와 교차하여 연결

현재 지원하는 GPS 모듈은 U-BLOX NEO-6M/7M/8M 모듈입니다. 추후 필요에 따라 다른 모듈도 추가될 수 있습니다.

#### 디버그 출력

`DEBUG` 포트는 기본적으로 비활성화되어 있으며, 사용자의 필요에 따라 커스텀할 수 있습니다.

기록된 로그를 콕핏 디스플레이 등 다른 MCU에 내보내기 위해 설계되었습니다.

전기적으로는 단순히 여분의 3.3V 0.5A 전원 레일과 GPIO 2개를 제공하는 커넥터이며, 사용자가 사용하기 나름입니다.

#### 디지털 및 아날로그

TMA-1은 4개의 디지털 입력 채널과 6개의 아날로그 입력 채널을 제공합니다. 또한, 총 2.5A를 공급할 수 있는 5V 전원 레일 5개를 제공합니다.

##### 디지털 입력

* LOW: 0 ~ 0.8V
* HIGH: 2.4 ~ 8.5V

디지털 채널은 순간적인 과전압은 버틸 수 있지만, 연속 입력 전압은 8.5V까지로 제한됩니다.

##### 아날로그 입력

아날로그 채널의 최대 입력 전압은 3.6V입니다.

한편, AIN1 ~ AIN4 채널은 선택 가능한 1/2 전압 분배 회로를 가지고 있습니다.
PCB에서 각 AIN 채널에 달린 점퍼를 합선시키면 전압 분배 회로가 활성화되며, 최대 입력 전압이 7.2V로 늘어납니다.

따라서, 최대 5V 전압을 출력하는 센서는 점퍼를 합선시킨 경우에만 사용할 수 있습니다.

AIN5와 AIN6에는 전압 분배 회로가 없으며, 최대 입력 전압은 3.6V로 고정됩니다.

### Control Hub

Control Hub는 [https://v2.monolith.luftaquila.io](https://v2.monolith.luftaquila.io) 에서 무료로 사용할 수 있습니다.

#### Live Telemetry

실시간 텔레메트리를 사용하려면 먼저 `Device Configuration` 탭에서 서버 정보를 설정해야 합니다.

또한, 수신되는 CAN 데이터를 보려면 먼저 `UI Configuration` 탭에서 CAN Decoder를 설정해야 합니다.

서버를 잘 설정했고 TMA-1이 네트워크에 연결되어 있다면 모든 기능은 알아서 잘 작동합니다.

GPS 카드에서 `Fix` / `No Fix` 태그로 위성 수신 상태를 확인할 수 있습니다. 궤적 표시 모드를 `Speed` (초록=저속, 빨강=고속) 또는 `Time` (남색=과거, 초록=최근)으로 전환할 수 있습니다.

##### Console

사용자 이벤트나 CAN 메시지를 장치로 전송할 수 있습니다.



* 사용자 이벤트
    * 사용자 이벤트는 주행 이후 데이터 리뷰에 도움이 되는 의미 있는 지점을 표시합니다.
    * 이벤트를 전송하려면 이름을 입력하고 전송 버튼을 누릅니다.
    * 이벤트 이름을 입력하지 않으면 `USREVT`로 기록됩니다.
    * 이벤트 이름은 16바이트 이하의 ASCII 문자열만 사용 가능합니다.
* CAN 메시지
    * 전송할 CAN 메시지 ID(11/29비트)와 데이터를 입력하고 전송 버튼을 클릭합니다.
    * 입력하지 않은 데이터 바이트들은 `0x00`으로 전송됩니다.

#### Data Viewer

주행 데이터를 열람하려면 먼저 기록을 다운로드해야 합니다.
`Device Configuration` 탭의 `Data Downloader` 섹션을 참고해 데이터를 다운로드합니다.

* `Select`를 눌러 다운받은 `*.log` 파일을 엽니다.
* `Graph` 카드에서 입력 카테고리 버튼이나 범례의 신호 이름을 눌러 그래프를 활성화합니다.
* `GPS` 카드에서 차량의 이동 궤적을 색상 그라디언트로 확인할 수 있습니다. `Speed` (초록=저속, 빨강=고속) 또는 `Time` (남색=과거, 초록=최근) 모드로 전환할 수 있으며, 슬라이더를 조절하면 특정 시점의 위치, 속도, 방위각을 볼 수 있습니다.
* `CAN` 카드에서 기록된 CAN 메시지의 통계를 확인할 수 있습니다: 메시지 ID, 총 수신 횟수, 평균 주기(Hz / ms), DLC, 마지막 데이터 바이트를 표시합니다.

기록된 CAN 데이터를 보려면 `UI Configuration` 탭에서 CAN Decoder를 먼저 설정해야 합니다.

#### UI Configuration

Live Telemetry와 Data Viewer의 각 카드의 표시 여부를 조정하거나 입력 신호의 이름과 단위, 배율을 설정할 수 있습니다.

변경 사항을 적용하려면 페이지를 새로고침해야 합니다.

##### Import/Export

현재 UI 설정을 내보내고 다른 기기나 브라우저에서 가져올 수 있습니다.

##### Display

Live Telemetry 및 Data Viewer에서 각 카드의 표시 여부를 제어합니다.

##### Units

아날로그 및 CAN 데이터에 사용할 사용자 정의 단위를 관리합니다.

##### Digital

채널 이름을 변경할 수 있습니다.

##### Analog



* `Name`: 그래프에 표시할 이름
* `Voltage Divider`: PCB에서 해당 채널의 전압 분배 점퍼를 연결한 경우 스위치를 켭니다.
* `Multiplier`: 측정된 실제 전압에 곱해지는 값입니다. 다음과 같은 경우에 수정합니다.
    * 센서에 추가 전압 분배 회로가 있는 경우
    * 원래 물리량을 계산하는 수식이 있는 경우
* `Unit`: 해당 데이터의 단위. 적절한 단위가 없다면 `Units` 카드에서 추가합니다.

##### CAN

CAN 메시지 디코더를 관리합니다. 디코더는 CAN 페이로드에서 유효한 데이터를 추출합니다.



* `Name`: 그래프에 표시할 이름
* `CAN Message ID`: 원하는 데이터가 포함된 CAN 메시지 ID
* `Multiplier`: 원본 값에 곱할 배율
* `Offset`: 곱셈 후 더할 값. 최종 값은 `multiplier × 원본 + offset`이며, 기본값은 `0`입니다.
* `Unit`: 해당 데이터의 단위. 적절한 단위가 없다면 `Units` 카드에서 추가합니다.
* `Data Range`: CAN 페이로드에서 데이터가 포함된 범위
    * CAN 페이로드는 최대 8바이트입니다.
        * `Byte` 모드: #0 ~ #7
        * `Bit` 모드: #0 ~ #63
        * 단일 바이트나 비트를 선택하려면 시작과 끝 값을 동일하게 설정합니다.
* `Data Signedness`
    * `Unsigned`: 데이터를 부호 없는 값으로 해석
    * `Signed`: 데이터를 부호 있는 2의 보수로 해석
* `Data Endianness`
    * `Byte` 모드에서만 선택 가능합니다.
    * 멀티바이트 데이터의 엔디언을 정의합니다.
* `Data Filter` / `Data Mask` (선택): CAN 페이로드 내용으로 메시지를 필터링하는 HEX 값입니다. `(data & mask) == filter` 조건을 만족하는 메시지만 디코딩됩니다. 둘 다 함께 입력하거나 모두 비워야 합니다.

#### Device Configuration

Control Hub가 연결할 서버와 장치 설정을 변경합니다.

장치가 인터넷에 연결되어 있다면 설정값을 자동으로 불러옵니다.

##### Server

* `Address`: Control Hub가 사용할 서버 주소
* `Name` / `Key`: 채널 이름 및 키

모든 값은 `TMA-1 - 초기 설정` 단계에서 장치에 입력한 값과 일치해야 합니다.

저장 버튼을 누르면 자동으로 서버에 연결합니다.

##### Device

* `SSID` / `Password`: TMA-1이 연결할 Wi-Fi 네트워크
* `Timezone`: 지역에 맞는 POSIX 타임존 문자열. [변환기](https://phpsecu.re/tz/)의 `TZ_INFO` 값을 사용하세요.
    * 이 값은 로그 파일 이름에 사용될 시간대를 결정합니다. 기록되는 데이터들의 시간은 UTC를 사용하므로 무관합니다.
* `T. Interval`: 텔레메트리 전송 주기

##### Inputs

디지털 및 아날로그 입력 채널의 로깅 여부를 제어합니다.

##### CAN

* `Enabled`: CAN 버스 로깅 여부
* `Bit rate`: CAN 버스의 Baud rate
* `Filter`: 수신할 메시지 ID (11/29비트)
* `Mask`: 필터의 각 비트에 대한 통과 규칙
    * `0`: 해당하는 필터 비트가 일치해야 통과
    * `1`: 해당하는 필터 비트 값을 무시 (don’t care)

`Filter`와 `Mask`에 대한 자세한 내용은 [ESP32-S3 API Reference](https://docs.espressif.com/projects/esp-idf/en/v5.4.2/esp32s3/api-reference/peripherals/twai.html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)의 *Acceptance Filter* 항목을 참고하세요. 기본 설정은 모든 CAN 메시지를 허용합니다.

##### GPS

* `Enabled`: GPS 위치 로깅 여부
* `Device`: GPS 모듈 종류를 선택합니다. 현재는 `UBLOX`만 사용 가능합니다.

##### [Danger Zone](https://www.youtube.com/watch?v=siwpn14IE7E)

* `Refresh`: 장치 설정값을 다시 불러옵니다.
    * 변경된 설정은 장치를 재시작해야 적용됩니다.
    * 재시작하기 전에 새로고침하면 이전 설정값이 다시 로드됩니다.
* `Restart`: 장치 재시작
* `Reset`: 장치 초기화 (PCB의 `RST` 점퍼를 합선시키는 것과 동일)

##### Data Downloader



* `Load List`: 현재 세션을 제외한 모든 로그 파일 목록을 불러옵니다.
* `Delete All`: 현재 세션을 제외한 모든 로그 파일을 삭제합니다.

파일 목록을 불러온 뒤, 원하는 파일의 다운로드 버튼을 눌러 해당 파일을 다운로드합니다.

## Development

직접 소프트웨어를 고쳐 사용하고 싶은 경우에만 필요합니다.

<details>

<summary>세부 사항</summary>

<h3>펌웨어</h3>

1. [GitHub 저장소](https://github.com/luftaquila/monolith)에 ⭐를 누릅니다.
1. [ESP-IDF](https://docs.espressif.com/projects/esp-idf/en/stable/esp32s3/get-started/index.html)를 설치하고 아래 명령을 실행합니다.

```
git clone https://github.com/luftaquila/monolith.git
cd monolith/device/firmware
make build
make run   # build & flash
```

<h3>Control Hub</h3>

1. [GitHub 저장소](https://github.com/luftaquila/monolith)에 ⭐를 누릅니다.
1. 아래 명령을 실행합니다.

```
git clone https://github.com/luftaquila/monolith.git
cd monolith/web
npm install
npm run vite
npm run build
```

</details>

## 스폰서

모노리스의 모든 PCB는 PCBWay로부터 프로토타이핑을 지원받아 완성되었습니다.



PCBWay의 경우 PCB 색상으로 흰색과 검은색, 매트 색상을 선택하면 구리 간 최소 간격이 0.22mm 이상이어야 합니다. 가장 최근에 지원받은 v2 mini PCB의 경우 가속도 센서로 사용되는 MPU-6500의 핀 간격이 0.2mm입니다. 검은색으로 주문했으나 이러한 이유로 불가하다는 메일을 받았고, 가장 간단한 해결책은 색깔을 초록, 파랑, 빨강, 보라 중 하나로 변경하는 것이라 가장 안 흔한 보라색으로 선택했습니다.



이후 견적 안내, BOM 리스트, 부품 문제 안내 메일을 순서대로 받았고 정상적으로 주문되었습니다. 제작이 완료된 후에는 보드 실물 사진을 다시 메일로 받았고, 주문부터 배송 출발까지는 정확히 2주 소요되었습니다.



배송받은 PCB는 10장 모두 정전기 방지 포장재에 한 장씩 개별포장되어 왔는데, 항상 뽁뽁이에 감겨 오는것만 보다 개별포장된걸 보니 놀라웠습니다. 테스트해본 기판은 정상작동했고, 모든 SMD 부품은 솔더브릿지같은 문제 없이 잘 실장되어 왔습니다. 실장하지 않은 부품에도 풋프린트 위에 납이 입혀져 와 손으로 납땜하기 쉬웠으며, 보라색 색깔도 아주 맘에 들었습니다.

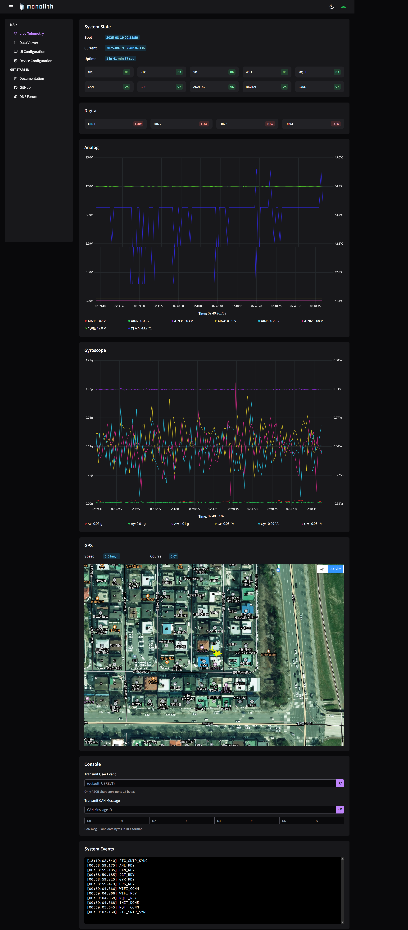
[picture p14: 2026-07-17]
docs/images/live.png

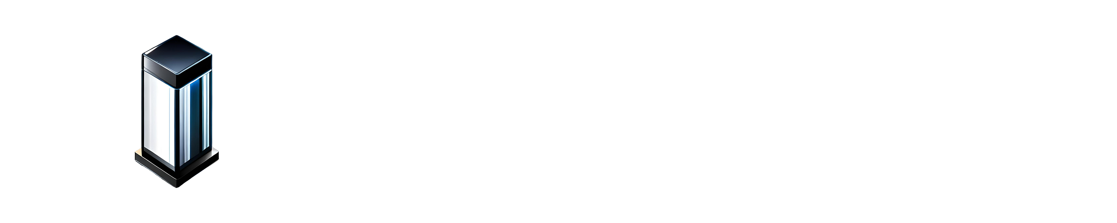
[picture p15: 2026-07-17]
.github/assets/wide-white.png

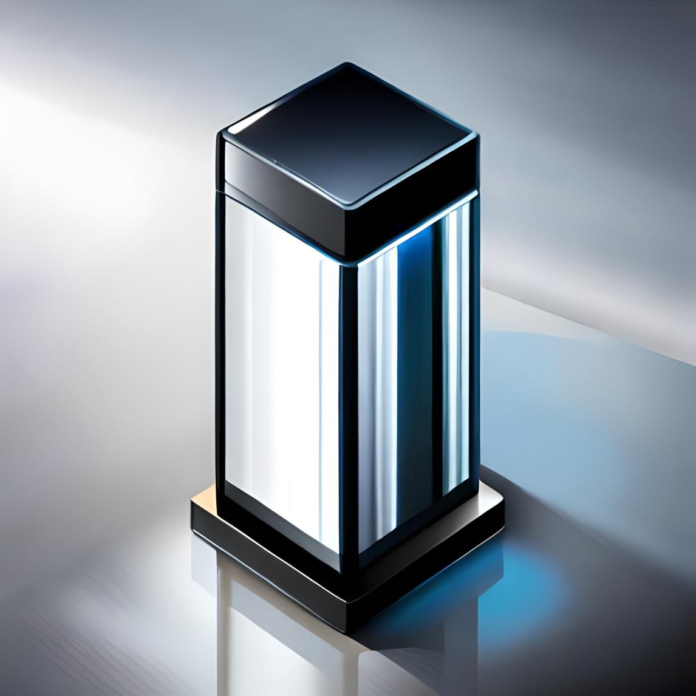
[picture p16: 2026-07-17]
.github/assets/original.jpg

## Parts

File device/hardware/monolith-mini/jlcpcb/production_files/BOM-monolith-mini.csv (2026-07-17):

Comment | Designator | Footprint | LCSC | Quantity
SN65HVD230 | U4 | SOIC-8_3.9x4.9mm_P1.27mm | C12084 | 1
10uF | C6 | C_1206_3216Metric | C13585 | 1
0.1uF | C11,C18,C19,C29,C38,C39,C4 | C_0603_1608Metric | C14663 | 7
1uF | C5 | C_0603_1608Metric | C15849 | 1
20pF | C24,C25 | C_0603_1608Metric | C1648 | 2
22uH | L1 | L_Sunlord_MWSA0603S | C177244 | 1
10uF | C1,C21 | C_0603_1608Metric | C19702 | 2
H5VLD3B | D9 | D_SOD-323 | C20615805 | 1
22nF | C26,C37 | C_0603_1608Metric | C21122 | 2
1k | R8 | R_0603_1608Metric | C21190 | 1
SS8050 | Q1,Q2 | SOT-23 | C2150 | 2
100 | R34 | R_0603_1608Metric | C22775 | 1
120 | R19 | R_0603_1608Metric | C22787 | 1
15k | R29 | R_0603_1608Metric | C22809 | 1
RED | D3 | LED_0603_1608Metric | C2286 | 1
3.3k | R26 | R_0603_1608Metric | C22978 | 1
4.7k | R33,R37 | R_0603_1608Metric | C23162 | 2
430 | R30 | R_0603_1608Metric | C23170 | 1
10k | R13,R14,R15,R18,R20,R21,R24,R25,R40,R41,R5 | R_0603_1608Metric | C25804 | 11
ESP32-S3-WROOM-1-N4 | U2 | ESP32-S3-WROOM-1 | C2913197 | 1
FC135 | Y1 | Crystal_SMD_3215-2Pin_3.2x1.5mm | C32346 | 1
BAT54C | D12 | SOT-23 | C37704 | 1
Micro_SD_Card | J13 | TF115BCP9 | C393941 | 1
MPU-6500 | U7 | QFN40P300X300X95-25N-D | C50278 | 1
10nF | C20,C9 | C_0603_1608Metric | C57112 | 2
22uF | C23 | C_0603_1608Metric | C59461 | 1
AMS1117-3.3 | U8 | SOT-223-3_TabPin2 | C6186 | 1
CR1220 | BT1 | S8411-45R_1 | C70381 | 1
PCF8563T | U11 | SOIC-8_3.9x4.9mm_P1.27mm | C7440 | 1
LMV321 | U10 | SOT-23-5 | C7972 | 1
SS34 | D6 | D_SMA | C8678 | 1
47uF | C12,C15,C16,C17 | C_1206_3216Metric | C96123 | 4
TPS5430DDA | U5 | TI_SO-PowerPAD-8_ThermalVias | C9864 | 1

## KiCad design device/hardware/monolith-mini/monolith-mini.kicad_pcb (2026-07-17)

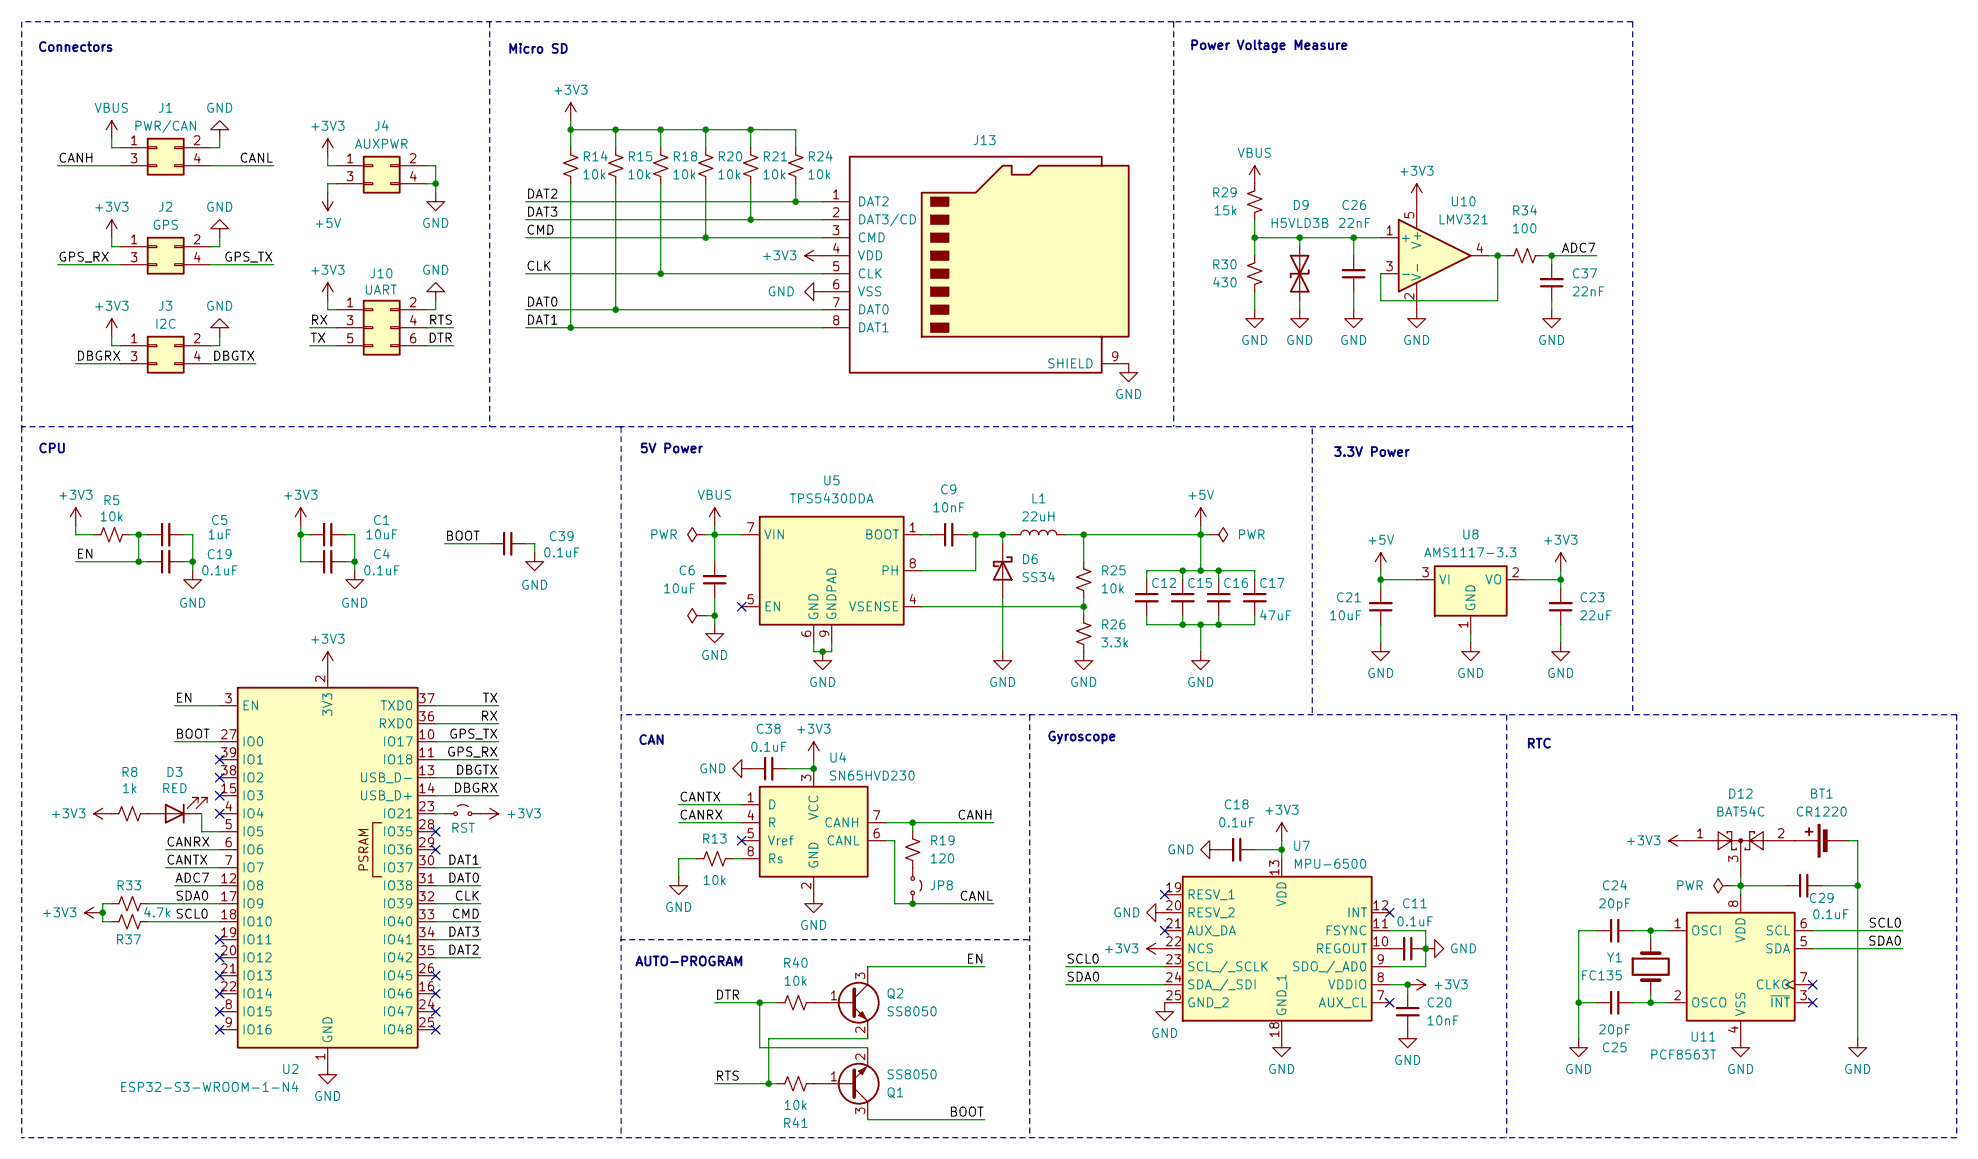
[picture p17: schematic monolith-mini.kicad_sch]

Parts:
BT1: CR1220; S8411-45R_1; Manufacturer_Part_Number CR1220-2; LCSC C70381
C1, C21: 10uF; C_0603_1608Metric; LCSC C19702
C4, C11, C18, C19, C29, C38, C39: 0.1uF; C_0603_1608Metric; LCSC C14663
C5: 1uF; C_0603_1608Metric; LCSC C15849
C6: 10uF; C_1206_3216Metric; LCSC C13585
C9, C20: 10nF; C_0603_1608Metric; LCSC C57112
C12, C15, C16, C17: 47uF; C_1206_3216Metric; LCSC C96123
C23: 22uF; C_0603_1608Metric; LCSC C59461
C24, C25: 20pF; C_0603_1608Metric; LCSC C1648
C26, C37: 22nF; C_0603_1608Metric; LCSC C21122
D3: RED; LED_0603_1608Metric; LCSC C2286
D6: SS34; D_SMA; LCSC C8678
D9: H5VLD3B; D_SOD-323; LCSC C20615805
D12: BAT54C; SOT-23; Manufacturer_Part_Number BAT54C; LCSC C37704
J1: PWR/CAN; Molex_Mini-Fit_Jr_5569-04A2_2x02_P4.20mm_Horizontal
J2: GPS; Molex_Mini-Fit_Jr_5569-04A2_2x02_P4.20mm_Horizontal
J3: I2C; Molex_Mini-Fit_Jr_5569-04A2_2x02_P4.20mm_Horizontal
J4: AUXPWR; Molex_Mini-Fit_Jr_5569-04A2_2x02_P4.20mm_Horizontal
J10: UART; PinHeader_2x03_P2.54mm_Vertical
J13: Micro_SD_Card; TF115BCP9; LCSC C393941
JP5: RST; PinHeader_1x02_P2.54mm_Vertical
JP8: CAN 120Ω; PinHeader_1x02_P2.54mm_Vertical
L1: 22uH; L_Sunlord_MWSA0603S; LCSC C177244
Q1, Q2: SS8050; SOT-23; LCSC C2150
R5, R13, R14, R15, R18, R20, R21, R24, R25, R40, R41: 10k; R_0603_1608Metric; LCSC C25804
R8: 1k; R_0603_1608Metric; LCSC C21190
R19: 120; R_0603_1608Metric; LCSC C22787
R26: 3.3k; R_0603_1608Metric; LCSC C22978
R29: 15k; R_0603_1608Metric; LCSC C22809
R30: 430; R_0603_1608Metric; LCSC C23170
R33, R37: 4.7k; R_0603_1608Metric; LCSC C23162
R34: 100; R_0603_1608Metric; LCSC C22775
U2: ESP32-S3-WROOM-1-N4; ESP32-S3-WROOM-1; LCSC C2913197
U4: SN65HVD230; SOIC-8_3.9x4.9mm_P1.27mm; LCSC C12084
U5: TPS5430DDA; TI_SO-PowerPAD-8_ThermalVias; LCSC C9864
U7: MPU-6500; QFN40P300X300X95-25N-D; Manufacturer_Part_Number MPU-6500; Mouser Part Number 410-MPU-6500
U8: AMS1117-3.3; SOT-223-3_TabPin2; LCSC C6186
U10: LMV321; SOT-23-5; LCSC C7972
U11: PCF8563T; SOIC-8_3.9x4.9mm_P1.27mm; LCSC C7440
Y1: FC135; Crystal_SMD_3215-2Pin_3.2x1.5mm; LCSC C32346

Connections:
+3V3: C1.1, C4.1, C18.1, C20.1, C23.2, C38.2, D12.1, J2.1, J3.1, J4.1, J10.1, J13.4 (VDD), JP5.2 (B), R5.2, R8.1, R14.2, R15.2, R18.2, R20.2, R21.2, R24.2, R33.1, R37.2, U2.2 (3V3), U4.3 (VCC), U7.8 (VDDIO), U7.13 (VDD), U7.22 (NCS), U8.2 (VO), U10.5 (V+)
+5V: C12.1, C15.1, C16.1, C17.1, C21.2, J4.3, L1.2, R25.2, U8.3 (VI)
/ADC7: C37.2, R34.2, U2.12 (IO8)
/BOOT: C39.1, Q1.3 (C), U2.27 (IO0)
/CANH: J1.3, R19.2, U4.7 (CANH)
/CANL: J1.4, JP8.2 (B), U4.6 (CANL)
/CANRX: U2.6 (IO6), U4.4 (R)
/CANTX: U2.7 (IO7), U4.1 (D)
/CLK: J13.5 (CLK), R18.1, U2.32 (IO39)
/CMD: J13.3 (CMD), R20.1, U2.33 (IO40)
/DAT0: J13.7 (DAT0), R15.1, U2.31 (IO38)
/DAT1: J13.8 (DAT1), R14.1, U2.30 (IO37)
/DAT2: J13.1 (DAT2), R24.1, U2.35 (IO42)
/DAT3: J13.2 (DAT3/CD), R21.1, U2.34 (IO41)
/DBGRX: J3.3, U2.14 (USB_D+)
/DBGTX: J3.4, U2.13 (USB_D-)
/DTR: J10.6, Q1.2 (E), R40.1
/EN: C5.1, C19.1, Q2.3 (C), R5.1, U2.3 (EN)
/GPS_RX: J2.3, U2.11 (IO18)
/GPS_TX: J2.4, U2.10 (IO17)
/RTS: J10.4, Q2.2 (E), R41.2
/RX: J10.3, U2.36 (RXD0)
/SCL0: R37.1, U2.18 (IO10), U7.23 (SCL_/_SCLK), U11.6 (SCL)
/SDA0: R33.2, U2.17 (IO9), U7.24 (SDA_/_SDI), U11.5 (SDA)
/TX: J10.5, U2.37 (TXD0)
GND: BT1.2 (-), C1.2, C4.2, C5.2, C6.1, C11.1, C12.2, C15.2, C16.2, C17.2, C18.2, C19.2, C20.2, C21.1, C23.1, C24.1, C25.1, C26.1, C29.2, C37.1, C38.1, C39.2, D6.2 (A), D9.2 (A2), J1.2, J2.2, J3.2, J4.2, J4.4, J10.2, J13.6 (VSS), J13.9 (SHIELD), R13.1, R26.1, R30.1, U2.1 (GND), U2.40 (GND), U2.41 (GND), U4.2 (GND), U5.6 (GND), U5.9 (GNDPAD), U7.9 (SDO_/_AD0), U7.11 (FSYNC), U7.18 (GND_1), U7.20 (RESV_2), U7.25 (GND_2), U8.1 (GND), U10.2 (V-), U11.4 (VSS)
unnamed: BT1.1 (+), D12.2
unnamed: D3.2 (A), R8.2
unnamed: D3.1 (K), U2.5 (IO5)
unnamed: C9.2, D6.1 (K), L1.1, U5.8 (PH)
unnamed: C26.2, D9.1 (A1), R29.1, R30.2, U10.1 (+)
unnamed: JP5.1 (A), U2.23 (IO21)
unnamed: JP8.1 (A), R19.1
unnamed: Q1.1 (B), R41.1
unnamed: Q2.1 (B), R40.2
unnamed: R13.2, U4.8 (Rs)
unnamed: C9.1, U5.1 (BOOT)
unnamed: R25.1, R26.2, U5.4 (VSENSE)
unnamed: C11.2, U7.10 (REGOUT)
unnamed: R34.1, U10.3 (-), U10.4
unnamed: C24.2, U11.1 (OSCI), Y1.1
unnamed: C25.2, U11.2 (OSCO), Y1.2
unnamed: C29.1, D12.3, U11.8 (VDD)
VBUS: C6.2, J1.1, R29.2, U5.7 (VIN)

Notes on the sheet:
CAN
AUTO-PROGRAM
Micro SD
Connectors
3.3V Power
RTC
Power Voltage Measure
CPU
Gyroscope
5V Power

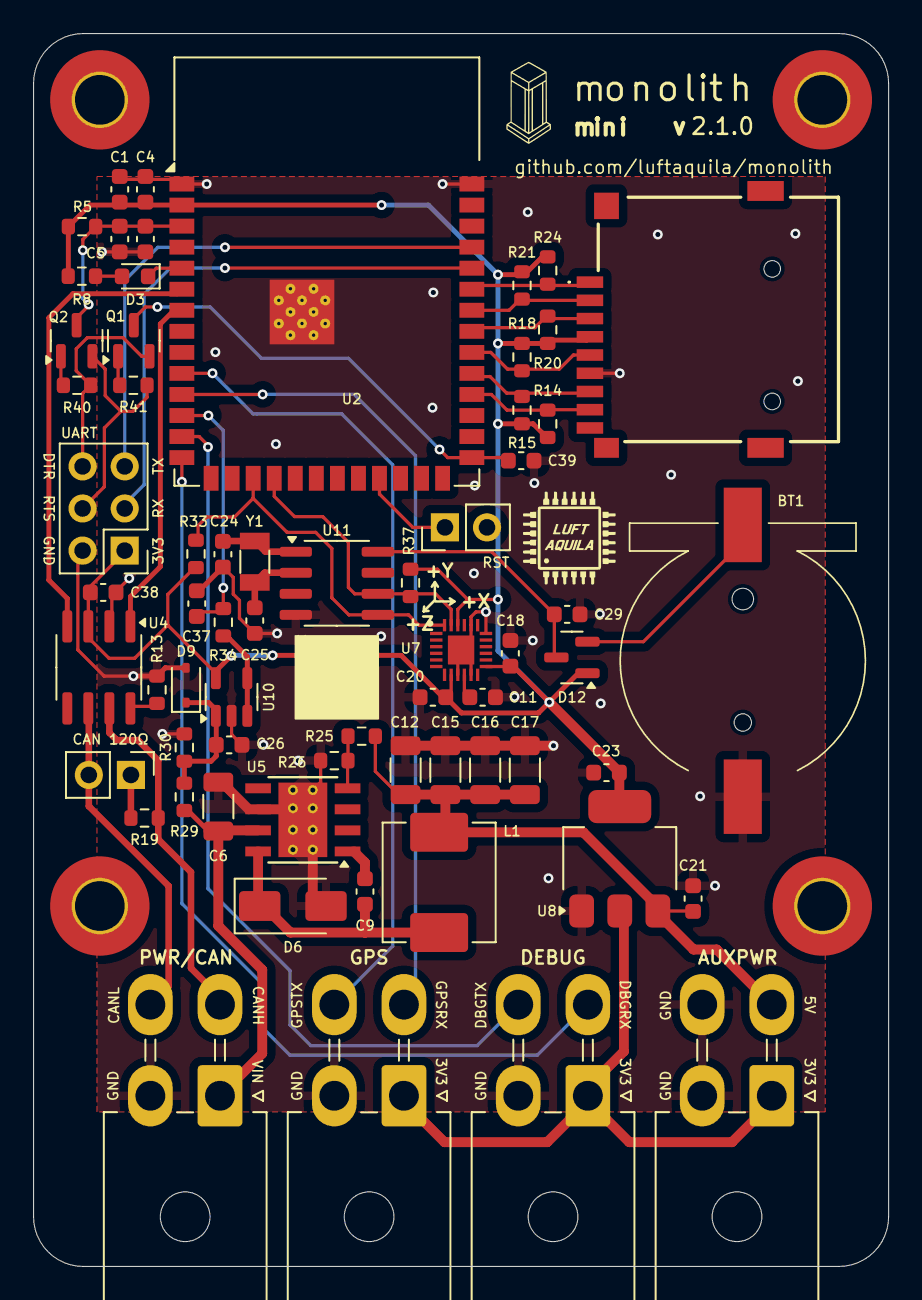
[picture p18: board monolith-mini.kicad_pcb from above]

Board: 2 copper layers, 51.6 x 74.4 mm, 65 parts (0 on the bottom side), 44 nets.

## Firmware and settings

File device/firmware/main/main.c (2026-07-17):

#include <sys/time.h>
#include <time.h>

#include <stdbool.h>

#include "main.h"

#include "driver/gpio.h"
#include "driver/i2c_master.h"
#include "esp_mac.h"
#include "nvs_flash.h"

/***** global variables *****/
struct timeval boot;
nvs_handle_t nvs;
TaskHandle_t led;
QueueHandle_t logqueue;
QueueHandle_t syslogqueue;
QueueHandle_t canlogqueue;
QueueHandle_t cantxqueue;

nvs_storage_t storage;

state_t init = 0;

const char components[][8] = { "CORE", "NVS", "RTC", "SD", "WIFI", "MQTT", "CAN", "GPS", "ANALOG", "DIGITAL", "GYRO" };

/***** function prototypes *****/
void sdcard_init(void);
void mqtt_init(void);
bool network_init(void);
static void core_init(void);
static void nvs_init(void);
static void rtc_init(void);
static void peripheral_task_init(void);

void task_can(void *pvParameters);
void task_gps(void *pvParameters);
void task_analog(void *pvParameters);
void task_digital(void *pvParameters);
void task_gyroscope(void *pvParameters);
static void task_led(void *pvParameters);

static void reset_isr(void *arg);

/*******************************************************************************
 * main application entry point
 ******************************************************************************/
void app_main(void) {
  logbuf.run = ALL_ERROR_FATAL;
  /*** Core GPIO ***/
  core_init();

  /*** NVS ***/
  nvs_init();

  /*** RTC ***/
  rtc_init();

  /*** SDIO ***/
  sdcard_init();

  /*** peripherals ***/
  peripheral_task_init();

  /*** Wi-Fi ***/
  if (network_init()) {
    /*** MQTT ***/
    mqtt_init();
  }

  SYSLOG("INIT_DONE");
}

/*******************************************************************************
 * configuration reset button handler
 ******************************************************************************/
static void reset_isr(void *arg) {
  static int64_t press = 0;

  if (gpio_get_level(GPIO_NUM_21) == true) {
    press = esp_timer_get_time();
  } else if (esp_timer_get_time() - press > 3000000) {
    nvs_erase_all(nvs);
    nvs_commit(nvs);
    esp_restart();
  }
}

/*******************************************************************************
 * system status LED indicator
 ******************************************************************************/
static void task_led(void *pvParameters) {
  uint32_t led_state            = true;
  state_led_interval_t interval = STATE_OK;

  while (true) {
    if (logbuf.run & (COMPONENT_ALL << COMPONENT_MAX)) {
      interval = STATE_FATAL;
    } else if (logbuf.run & COMPONENT_ALL) {
      interval = STATE_ERROR;
    } else {
      interval = STATE_OK;
    }

    led_state = !led_state;
    gpio_set_level(GPIO_NUM_5, led_state);

    vTaskDelay(interval);
  }
}

/*******************************************************************************
 * init core GPIO and LED task
 ******************************************************************************/
static void core_init(void) {
  gpio_config_t gpio;

  /*** LED ***/
  gpio.pin_bit_mask = (1ULL << GPIO_NUM_5);
  gpio.mode         = GPIO_MODE_OUTPUT_OD;
  gpio.intr_type    = GPIO_INTR_DISABLE;
  gpio.pull_up_en   = GPIO_PULLUP_DISABLE;
  gpio.pull_down_en = GPIO_PULLDOWN_DISABLE;

  if (gpio_config(&gpio) != ESP_OK || xTaskCreate(task_led, "led", 2048, NULL, 5, &led) != pdPASS) {
    ERROR_LOG(&init, CORE, "LED config failure");
  }

  /*** RST ***/
  gpio.pin_bit_mask = (1ULL << GPIO_NUM_21);
  gpio.mode         = GPIO_MODE_INPUT;
  gpio.intr_type    = GPIO_INTR_ANYEDGE;
  gpio.pull_down_en = GPIO_PULLDOWN_ENABLE;

  esp_err_t ret = gpio_config(&gpio);
  ret |= gpio_install_isr_service(0);
  ret |= gpio_isr_handler_add(GPIO_NUM_21, reset_isr, NULL);

  if (ret != ESP_OK) {
    ERROR_LOG(&init, CORE, "RST config failure");
  }

  if (IS_OK(&init, CORE)) {
    CLEAR_ALL(&logbuf.run, CORE);
  } else {
    COPY_STATE(&logbuf.run, &init, CORE);
  }
}

/*******************************************************************************
 * init NVS and set default values
 ******************************************************************************/
static void nvs_init(void) {
  if (nvs_flash_init() != ESP_OK) {
    FATAL_LOG(&init, NVS, "NVS flash init failure");
    goto finish;
  }

  if (nvs_open("storage", NVS_READWRITE, &nvs) != ESP_OK) {
    FATAL_LOG(&init, NVS, "open failure");
    goto finish;
  }

  // set wifi default values
  esp_read_mac(storage.wifi.mac, ESP_MAC_WIFI_STA);
  snprintf(storage.wifi.macaddr, sizeof(storage.wifi.macaddr), "%02X:%02X:%02X:%02X:%02X:%02X", storage.wifi.mac[0],
    storage.wifi.mac[1], storage.wifi.mac[2], storage.wifi.mac[3], storage.wifi.mac[4], storage.wifi.mac[5]);

  size_t len = sizeof(storage.wifi.ssid);

  if (nvs_get_str(nvs, "ssid", storage.wifi.ssid, &len) != ESP_OK) {
    storage.wifi.ssid[0] = '\0';
    nvs_set_str(nvs, "ssid", "");
  }

  len = sizeof(storage.wifi.passwd);

  if (nvs_get_str(nvs, "passwd", storage.wifi.passwd, &len) != ESP_OK) {
    storage.wifi.passwd[0] = '\0';
    nvs_set_str(nvs, "passwd", "");
  }

  len = sizeof(storage.device.server);

  // set device configuration default values
  if (nvs_get_str(nvs, "server", storage.device.server, &len) != ESP_OK) {
    snprintf(storage.device.server, sizeof(storage.device.server), "v2.monolith.luftaquila.io");
    nvs_set_str(nvs, "server", storage.device.server);
  }

  len = sizeof(storage.device.name);

  if (nvs_get_str(nvs, "name", storage.device.name, &len) != ESP_OK) {
    snprintf(storage.device.name, sizeof(storage.device.name), "%02X%02X%02X%02X%02X%02X", storage.wifi.mac[0],
      storage.wifi.mac[1], storage.wifi.mac[2], storage.wifi.mac[3], storage.wifi.mac[4], storage.wifi.mac[5]);
    nvs_set_str(nvs, "name", storage.device.name);
  }

  len = sizeof(storage.device.key);

  if (nvs_get_str(nvs, "key", storage.device.key, &len) != ESP_OK) {
    snprintf(storage.device.key, sizeof(storage.device.key), "monolith");
    nvs_set_str(nvs, "key", storage.device.key);
  }

  len = sizeof(storage.device.key);

  // set device timezone default value
  if (nvs_get_str(nvs, "tz", storage.device.tz, &len) != ESP_OK) {
    snprintf(storage.device.tz, sizeof(storage.device.tz), "KST-9");
    nvs_set_str(nvs, "tz", storage.device.tz);
  }

  if (nvs_get_u32(nvs, "intv", &storage.device.intv) != ESP_OK) {
    nvs_set_u32(nvs, "intv", 500);
    storage.device.intv = 500;
  }

  // set peripheral enabled default values
  if (nvs_get_u8(nvs, "can_en", &storage.enabled.can) != ESP_OK) {
    nvs_set_u8(nvs, "can_en", true);
    storage.enabled.can = true;
  }

  if (nvs_get_u8(nvs, "gps_en", &storage.enabled.gps) != ESP_OK) {
    nvs_set_u8(nvs, "gps_en", true);
    storage.enabled.gps = true;
  }

  if (nvs_get_u8(nvs, "anl_en", &storage.enabled.analog) != ESP_OK) {
    nvs_set_u8(nvs, "anl_en", true);
    storage.enabled.analog = true;
  }

  if (nvs_get_u8(nvs, "dgt_en", &storage.enabled.digital) != ESP_OK) {
    nvs_set_u8(nvs, "dgt_en", true);
    storage.enabled.digital = true;
  }

  // set CAN default values
  if (nvs_get_u8(nvs, "can_bps", &storage.can.bps) != ESP_OK) {
    nvs_set_u8(nvs, "can_en", CAN_BPS_500K);
    storage.can.bps = CAN_BPS_500K;
  }

  if (nvs_get_u32(nvs, "can_filter", &storage.can.filter) != ESP_OK) {
    nvs_set_u32(nvs, "can_en", 0x00000000);
    storage.can.filter = 0x00000000;  // accept all
  }

  if (nvs_get_u32(nvs, "can_mask", &storage.can.mask) != ESP_OK) {
    nvs_set_u32(nvs, "can_en", 0xFFFFFFFF);
    storage.can.mask = 0xFFFFFFFF;  // accept all
  }

  // set GPS default values
  if (nvs_get_u8(nvs, "gps_dev", &storage.gps.dev) != ESP_OK) {
    nvs_set_u8(nvs, "gps_dev", GPS_DEV_UBLOX);
    storage.gps.dev = GPS_DEV_UBLOX;
  }

  // commit changes
  if (nvs_commit(nvs) != ESP_OK) {
    ERROR_SYSLOG(&logbuf.run, NVS, "commit failure", "NVS_COMMIT_FAIL");
  }

finish:
  if (IS_OK(&init, NVS)) {
    CLEAR_ALL(&logbuf.run, NVS);
  } else {
    COPY_STATE(&logbuf.run, &init, NVS);
  }
}

/*******************************************************************************
 * init RTC and set system time
 ******************************************************************************/
static void rtc_init(void) {
  // set timezone
  setenv("TZ", "UTC", 1);
  tzset();

  i2c_master_bus_handle_t i2c0;
  i2c_master_bus_config_t i2c_config = {
    .clk_source                   = I2C_CLK_SRC_DEFAULT,
    .i2c_port                     = I2C_NUM_0,
    .scl_io_num                   = GPIO_NUM_10,
    .sda_io_num                   = GPIO_NUM_9,
    .glitch_ignore_cnt            = 7,
    .flags.enable_internal_pullup = false,
  };

  if (i2c_new_master_bus(&i2c_config, &i2c0) != ESP_OK) {
    ERROR_LOG(&init, RTC, "I2C init failure");
    goto finish;
  }

  i2c_master_dev_handle_t rtc;
  i2c_device_config_t rtc_cfg = {
    .dev_addr_length = I2C_ADDR_BIT_LEN_7,
    .device_address  = 0x51,
    .scl_speed_hz    = 100000,
  };

  if (i2c_master_bus_add_device(i2c0, &rtc_cfg, &rtc) != ESP_OK) {
    ERROR_LOG(&init, RTC, "device init failure");
    goto finish;
  }

  uint8_t tx[1] = { 0x02 };  // VL_seconds register address
  uint8_t rx[7] = { 0 };     // 0x02 VL_seconds to 0x08 Years register

  esp_err_t ret;
  int cnt = 0;

  do {
    ret = i2c_master_transmit_receive(rtc, tx, sizeof(tx), rx, sizeof(rx), I2C_TIMEOUT_MS);
    if (ret != ESP_OK) i2c_master_bus_reset(i2c0);
    cnt++;
  } while (ret != ESP_OK && cnt < 3);

  if (ret != ESP_OK) {
    i2c_master_bus_rm_device(rtc);
    FATAL_LOG(&init, RTC, "read time transfer failure");
    goto finish;
  }

  i2c_master_bus_rm_device(rtc);

  // rtc has valid time set
  if (rx[6] != 0x00) {
    struct tm tm = {
      .tm_sec  = BCD_TO_DEC(rx[0] & 0x7F),
      .tm_min  = BCD_TO_DEC(rx[1] & 0x7F),
      .tm_hour = BCD_TO_DEC(rx[2] & 0x3F),
      .tm_mday = BCD_TO_DEC(rx[3] & 0x3F),
      .tm_wday = BCD_TO_DEC(rx[4] & 0x07),
      .tm_mon  = BCD_TO_DEC(rx[5] & 0x1F) - 1,
      .tm_year = BCD_TO_DEC(rx[6]) + 100  // from 2000
    };

    time_t seconds = mktime(&tm);

    if (seconds == (time_t)-1) {
      ERROR_LOG(&init, RTC, "mktime failure");
      goto finish;
    }

    struct timeval tv = {
      .tv_sec  = seconds,
      .tv_usec = esp_timer_get_time() % 1000000,
    };

    settimeofday(&tv, NULL);
    INFO(RTC, "time set to %s", ctime(&tv.tv_sec));
  } else {
    ERROR_LOG(&init, RTC, "no valid time set");
    goto finish;
  }

finish:
  if (IS_OK(&init, RTC)) {
    CLEAR_ALL(&logbuf.run, RTC);
  } else {
    COPY_STATE(&logbuf.run, &init, RTC);
  }

  // read boot time
  gettimeofday(&boot, NULL);
}

/*******************************************************************************
 create peripheral recorder tasks
 ******************************************************************************/
static void peripheral_task_init(void) {
  /***** CAN *****/
  if (storage.enabled.can) {
    if (xTaskCreate(task_can, "can", 4096, NULL, 4, NULL) != pdPASS) {
      ERROR_SYSLOG(&init, CORE, "CAN task create failure", "CAN_TASK_FAIL");
    }
  } else {
    CLEAR_ALL(&logbuf.run, CAN);
  }

  /***** GPS *****/
  if (storage.enabled.gps) {
    if (xTaskCreate(task_gps, "gps", 4096, NULL, 5, NULL) != pdPASS) {
      ERROR_SYSLOG(&init, CORE, "GPS task create failure", "GPS_TASK_FAIL");
    }
  } else {
    CLEAR_ALL(&logbuf.run, GPS);
  }

  /***** ANALOG *****/
  if (storage.enabled.analog) {
    if (xTaskCreate(task_analog, "analog", 4096, NULL, 5, NULL) != pdPASS) {
      ERROR_SYSLOG(&init, CORE, "ANALOG task create failure", "ANL_TASK_FAIL");
    }
  } else {
    CLEAR_ALL(&logbuf.run, ANALOG);
  }

#ifndef CONFIG_MONOLITH_MINI
  /***** DIGITAL *****/
  if (storage.enabled.digital) {
    if (xTaskCreate(task_digital, "digital", 4096, NULL, 5, NULL) != pdPASS) {
      ERROR_SYSLOG(&init, CORE, "DIGITAL task create failure", "DGT_TASK_FAIL");
    }
  } else {
    CLEAR_ALL(&logbuf.run, DIGITAL);
  }
#else
  CLEAR_ALL(&logbuf.run, DIGITAL);
#endif

  /***** GYROSCOPE (always enabled) *****/
  if (xTaskCreate(task_gyroscope, "gyroscope", 4096, NULL, 5, NULL) != pdPASS) {
    ERROR_SYSLOG(&init, CORE, "GYROSCOPE task create failure", "GYR_TASK_FAIL");
  }
}

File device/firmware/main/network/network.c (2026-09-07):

#include <time.h>

#include "main.h"

#include "driver/i2c_master.h"
#include "esp_http_server.h"
#include "esp_netif_sntp.h"
#include "esp_wifi.h"

#define WIFI_CONNECTED_BIT (1 << 1)

void ap_start(void);  // webserver.c

static EventGroupHandle_t wifi_evt;
static bool sta_configured = false;

static void sntp_sync_callback(struct timeval *tv) {
  i2c_master_bus_handle_t i2c0;

  // i2c0 already initalized
  if (i2c_master_get_bus_handle(I2C_NUM_0, &i2c0) != ESP_OK) {
    ERROR_SYSLOG(&logbuf.run, RTC, "I2C get bus failure", "RTC_I2C_FAIL");
    return;
  }

  i2c_master_dev_handle_t rtc;
  i2c_device_config_t rtc_cfg = {
    .dev_addr_length = I2C_ADDR_BIT_LEN_7,
    .device_address  = 0x51,
    .scl_speed_hz    = 100000,
  };

  if (i2c_master_bus_add_device(i2c0, &rtc_cfg, &rtc) != ESP_OK) {
    ERROR_SYSLOG(&logbuf.run, RTC, "device init failure", "RTC_DEV_FAIL");
    return;
  }

  struct tm tp;
  struct tm *tm = gmtime_r(&tv->tv_sec, &tp);

  uint8_t tx[8];
  tx[0] = 0x02;                           // VL_seconds register address
  tx[1] = DEC_TO_BCD(tm->tm_sec);         // seconds
  tx[2] = DEC_TO_BCD(tm->tm_min);         // minutes
  tx[3] = DEC_TO_BCD(tm->tm_hour);        // hours
  tx[4] = DEC_TO_BCD(tm->tm_mday);        // day of month
  tx[5] = DEC_TO_BCD(tm->tm_wday);        // day of week
  tx[6] = DEC_TO_BCD(tm->tm_mon + 1);     // month
  tx[7] = DEC_TO_BCD(tm->tm_year - 100);  // year

  esp_err_t ret;
  int cnt = 0;

  do {
    ret = i2c_master_transmit(rtc, tx, sizeof(tx), I2C_TIMEOUT_MS);
    if (ret != ESP_OK) i2c_master_bus_reset(i2c0);
    cnt++;
  } while (ret != ESP_OK && cnt < 3);

  if (ret != ESP_OK) {
    ERROR_SYSLOG(&logbuf.run, RTC, "write time transfer failure", "RTC_WRITE_FAIL");
  } else {
    SYSLOG("RTC_SNTP_SYNC");
  }

  i2c_master_bus_rm_device(rtc);
  INFO(RTC, "SNTP time set to %s", ctime(&tv->tv_sec));
}

static void wifi_event_handler(void *arg, esp_event_base_t event_base, int32_t event_id, void *event_data) {
  if (event_base == WIFI_EVENT && event_id == WIFI_EVENT_STA_START) {
    if (sta_configured) esp_wifi_connect();
  }

  else if (event_base == WIFI_EVENT && event_id == WIFI_EVENT_STA_DISCONNECTED) {
    if (IS_OK(&logbuf.run, WIFI)) {
      char buf[sizeof(system_event_t)];
      snprintf(buf, sizeof(buf), "STA_LOST:%02X", ((wifi_event_sta_disconnected_t *)event_data)->reason);
      ERROR_SYSLOG(&logbuf.run, WIFI, buf, buf);
    }
    if (sta_configured) esp_wifi_connect();  // 계속 재시도 (AP는 항상 열려있으니 무해함)
  }

  else if (event_base == IP_EVENT && event_id == IP_EVENT_STA_GOT_IP) {
    xEventGroupSetBits(wifi_evt, WIFI_CONNECTED_BIT);
    CLEAR_ALL(&logbuf.run, WIFI);

    if (mqtt != NULL && IS_ERROR(&logbuf.run, MQTT)) {
      esp_mqtt_client_reconnect(mqtt);
    }

    // SNTP는 최초 1회만 초기화
    static bool sntp_started = false;
    if (!sntp_started) {
      esp_sntp_config_t sntp = ESP_NETIF_SNTP_DEFAULT_CONFIG("time.google.com");
      sntp.sync_cb           = sntp_sync_callback;
      esp_netif_sntp_init(&sntp);
      sntp_started = true;
    }

    SYSLOG("WIFI_CONN");
    INFO(WIFI, "connected to %s(" IPSTR ")", storage.wifi.ssid, IP2STR(&((ip_event_got_ip_t *)event_data)->ip_info.ip));
  }
}

bool network_init(void) {
  if (esp_netif_init() != ESP_OK || esp_event_loop_create_default() != ESP_OK) {
    ERROR_SYSLOG(&init, WIFI, "netif init failure", "NETIF_INIT_FAIL");
    return false;
  }

  esp_netif_create_default_wifi_ap();
  esp_netif_create_default_wifi_sta();

  wifi_init_config_t wifi_cfg = WIFI_INIT_CONFIG_DEFAULT();

  if (esp_wifi_init(&wifi_cfg) != ESP_OK) {
    ERROR_SYSLOG(&init, WIFI, "init failure", "WIFI_INIT_FAIL");
    return false;
  }

  wifi_evt = xEventGroupCreate();

  esp_event_handler_instance_t instance_any_id;
  esp_event_handler_instance_t instance_got_ip;
  esp_event_handler_instance_register(WIFI_EVENT, ESP_EVENT_ANY_ID, &wifi_event_handler, NULL, &instance_any_id);
  esp_event_handler_instance_register(IP_EVENT, IP_EVENT_STA_GOT_IP, &wifi_event_handler, NULL, &instance_got_ip);

  // ---- AP: 상시 on. SSID/PW 저장 여부와 무관하게 항상 켠다 ----
  wifi_config_t ap = {
    .ap = {
      .password       = "monolith",
      .max_connection = 4,
      .authmode       = WIFI_AUTH_WPA2_PSK,
    },
  };
  snprintf((char *)ap.ap.ssid, sizeof(ap.ap.ssid), "Monolith v2 %02X%02X%02X",
    storage.wifi.mac[3], storage.wifi.mac[4], storage.wifi.mac[5]);

  if (esp_wifi_set_mode(WIFI_MODE_APSTA) != ESP_OK || esp_wifi_set_config(WIFI_IF_AP, &ap) != ESP_OK) {
    ERROR_SYSLOG(&init, WIFI, "AP config failure", "AP_CFG_FAIL");
    return false;
  }

  // ---- STA: 저장된 자격증명이 있을 때만 설정. 없으면 연결 시도 자체를 안 함 ----
  sta_configured = strlen(storage.wifi.ssid) > 0 && strlen(storage.wifi.passwd) >= 8;

  if (sta_configured) {
    wifi_config_t sta = { 0 };
    snprintf((char *)sta.sta.ssid, sizeof(sta.sta.ssid), "%s", storage.wifi.ssid);
    snprintf((char *)sta.sta.password, sizeof(sta.sta.password), "%s", storage.wifi.passwd);
    sta.sta.scan_method        = WIFI_FAST_SCAN;
    sta.sta.threshold.authmode = WIFI_AUTH_WPA2_PSK;

    if (esp_wifi_set_config(WIFI_IF_STA, &sta) != ESP_OK) {
      ERROR_SYSLOG(&init, WIFI, "STA config failure", "STA_CFG_FAIL");
      sta_configured = false;
    }
  }

  if (esp_wifi_start() != ESP_OK) {
    ERROR_SYSLOG(&init, WIFI, "start failure", "WIFI_START_FAIL");
    return false;
  }

  // 포털 HTTP 서버 + 캡티브 DNS는 언제나 띄운다 (webserver.c)
  ap_start();

  // app_main()을 여기서 더 이상 블록하지 않음 — STA 연결 여부와 무관하게 바로 리턴,
  // MQTT는 이후 무조건 초기화되고 esp-mqtt가 내부적으로 IP 획득을 기다렸다가 붙는다.
  SYSLOG("WIFI_INIT_DONE");
  return true;
}

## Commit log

2026-07-17 Initial commit: existing EC2 server config
    [BOM-monolith-mini.csv, BOM-monolith.csv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]
2026-08-18 Handle zero case in split_range function
    Fix bug when d_min is 0 to prevent NaN step calculation.
2026-08-27 Remove unused section constants in device.vue
2026-08-31 Replace ANALOG with Steering in state.js
